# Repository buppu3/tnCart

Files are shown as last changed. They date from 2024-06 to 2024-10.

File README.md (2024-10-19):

# tnCart
TangNano20K を搭載した MSX 用カートリッジ。WonderTANG 対応版は [tnCartWonder](https://github.com/herraa1/tnCartWonder) をご参照ください。

- [カートリッジ基板](#カートリッジ基板)
- [たぶん動く機能](#たぶん動く機能)
- [今後の予定](#今後の予定)
- [対応する予定がない機能](#対応する予定がない機能)
- [使用モジュール](#使用モジュール)
- [メモ](#メモ)

## 使い方

- [FPGAビットストリーム、BIOSイメージのインストール方法](https://github.com/buppu3/tnCart/blob/main/doc/flash.md)
- [メガロムエミュレータの使い方](https://github.com/buppu3/tnCart/blob/main/doc/megarom.md)
- [機能のカスタマイズ](https://github.com/buppu3/tnCart/blob/main/doc/config.md)

## カートリッジ基板
回路は WonderTANG V1.01c のピンアサインとほぼ同じ(MSEL0_33 と MSEL1_33 が逆みたいです)で、バッファ IC は2電源タイプに変更してます。
また、信号の衝突を防ぐために INT 信号はオープンコレクタに変更してあります(WonderTANG V1.02d 相当)。

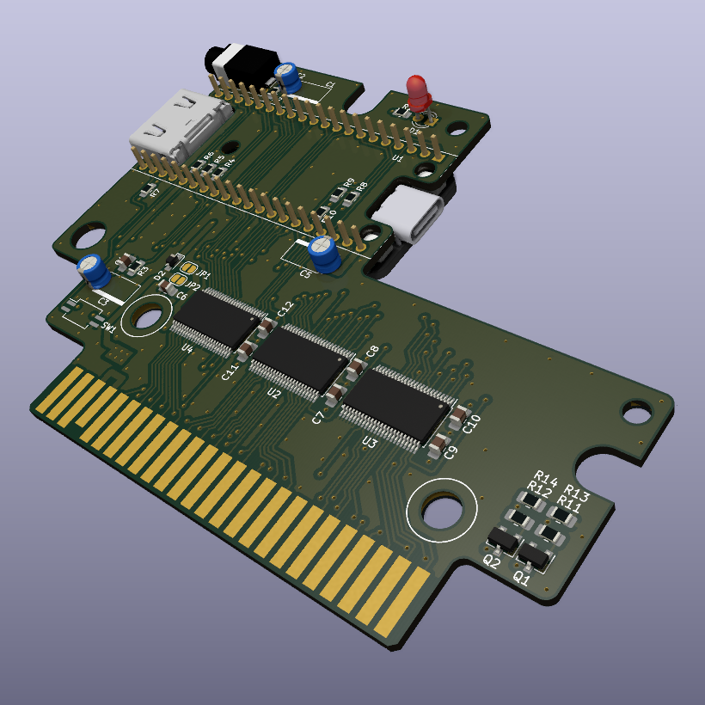
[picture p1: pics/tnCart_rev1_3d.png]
基板イメージ
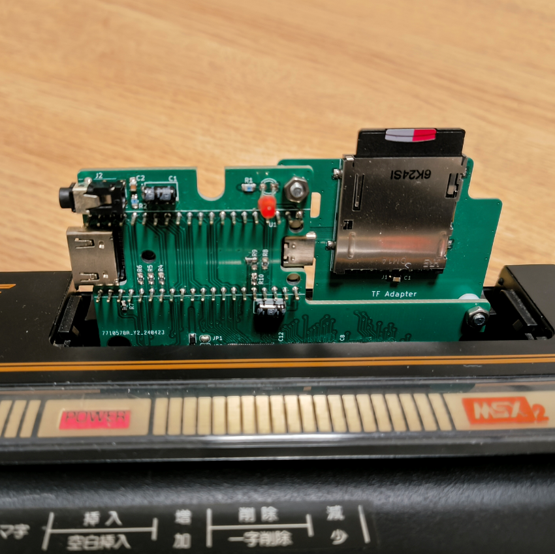
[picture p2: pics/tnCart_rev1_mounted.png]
スロットに装着したカートリッジ基板


## たぶん動く機能
- 4MB 拡張 RAM
- NEXTOR と TF カード制御
- メガロムエミュレーション
- SCC/SCC-I 音源
- FM 音源(OPLL)カートリッジ(拡張 BASIC は未対応)
- SCC + OPLL + PSG 音源の 3.5mmフォンジャック出力
- PAC 機能(~~まだデータ保持機能が実装されていませんので、電源を切るとデータは消えます~~)
- V9990 エミュレーション(「[msx-samurai](https://github.com/albs-br/msx-samurai)」,「[MSXgl](https://github.com/aoineko-fr/MSXgl) V9990サンプルの一部」,「[TINY野郎氏のテックデモ](https://www.youtube.com/watch?v=I6kXyMaED0s)」がそれなりに動く程度)

### MSXglサンプル
https://github.com/user-attachments/assets/6ccc81ad-7539-472d-90ff-44e20a4ad2ab

### msx-samurai
https://github.com/user-attachments/assets/eceabaee-c464-4074-b1bb-01007c4406e5

### TINY野郎氏のテックデモ1
https://github.com/user-attachments/assets/5c7b5b81-0413-4705-99fa-486552f4d58d

### TINY野郎氏のテックデモ2
https://github.com/user-attachments/assets/f6615e37-0041-4baa-8b7d-7cd3aba46d73

## 今後の予定
- V9990 のカーソル EOR 処理
- V9990 の B0(192x240) モード
- 回路と基板の修正(WS2812を点灯しないようにする等)

## 対応する予定がない機能
下記の機能は、しばらく(もしくは永遠に)対応する予定がありません
- V9990 の B5(640x400),B6(640x480)モード
- V9990 の画面補正機能(R#16)
- V9990 の漢字ROM
- HDMI による音声出力(ライセンス的に難しい)

## 使用モジュール
各機能の実装に下記モジュールを使用しています。
- PSG https://github.com/dnotq/ym2149_audio
- OPLL(VM2413) https://github.com/hra1129/one-chip-msx-kai/tree/main/source/pld/src/sound/opll/vm2413
- OPLL(IKAOPLL) https://github.com/ika-musume/IKAOPLL
- SCC(IKASCC) https://github.com/ika-musume/IKASCC

## メモ
- V9990 の映像は 720x480ドット(ピクセルクロック約27MHz) の DVI 信号で出力されます。接続するモニターやビデオキャプチャー機器によっては正常に動作しない可能性があります。

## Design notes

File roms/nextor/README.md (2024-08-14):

# NEXTOR カーネルロムイメージ

Nextor を使用する場合は、Gowin Programmer で EEPROM の 100000h へカーネル ROM を書いてください。
カーネル ROM ファイルは Nextor 公式( https://github.com/Konamiman/Nextor/releases )で配布されている "Nextor-2.1.2.MegaFlashSDSCC.1-slot.ROM" を使用してください。
ファイルの拡張子を全て小文字で bin へ変更しないと Gowin Programmer が正常に動作しませんので注意してください。

When using Nextor, you must write the ROM file to address 100000h using "Gowin Programmer".
The current version works with the officially distributed ROM file "Nextor-2.1.2.MegaFlashSDSCC.1-slot.ROM".
Gowin Programmer will not work properly unless you change the ROM file extension to ".bin".

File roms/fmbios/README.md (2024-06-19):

## FM BIOS ROM

アプリケーションに OPLL を検出させるための ROM ファイルです。
拡張 BASIC や ROM 内蔵音色は使用できません。

ファイルの拡張子を全て .rom から .bin へ変更し、Gowin Programmer を使用して 120000h へ書き込んでください。

This is a ROM file that allows applications to detect OPLL.
When using OPLL, you need to write this ROM file to address 120000h using "Gowin Programmer".

This ROM does not support BASIC statements and instrument data read from the ROM.
Gowin Programmer will not work properly unless you change the ROM file extension to ".bin".

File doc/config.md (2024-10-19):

## 機能のカスタマイズ
機能の設定、メモリ配置は config.sv で変更できます。ファイルを変更後、GowinSynthesis でビットストリームを合成してください。合成時、機能の有無でタイミング制約ファイル(sdcファイル)がエラーになりますので、適宜修正してください。

### フラッシュメモリ
FLASH_ADDR_, FLASH_SIZE_ パラメータで各機能に使われるフラッシュメモリのアドレスとサイズを設定できます。

### SDRAM
RAM_ADDR_ パラメータで各機能に使われる RAM のアドレスを設定できます。

### 音量バランス
ATT_EXT_ パラメータで 3.5mm フォンジャック出力の調整、ATT_INT_ パラメータで本体音声の調整ができます。  
MUL と DIV の比率で指定します。例えば出力を 0.5倍にするときは、MUL = 1, DIV = 2 を指定してください。

| パラメータ | 内容 |
| --- | --- |
| ATT_EXT_PSG_MUL<br/>ATT_EXT_PSG_DIV | PSG 音源 3.5mm フォンジャック出力 |
| ATT_EXT_FM_MUL<br/>ATT_EXT_FM_DIV | FM 音源 3.5mm フォンジャック出力  |
| ATT_EXT_MEGAROM_MUL<br/>ATT_EXT_MEGAROM_DIV | SCC 音源 3.5mm フォンジャック出力 |
| ATT_INT_FM_MUL<br/>ATT_INT_FM_DIV | FM 音源 本体出力 |
| ATT_INT_MEGAROM_MUL<br/>ATT_INT_MEGAROM_DIV | SCC 音源 本体出力 |

### 機能の ON/OFF
ENABLE_* パラメータで各機能の ENABLE/DISABLE を設定できます。
| パラメータ | 内容 |
| --- | --- |
| ENABLE_MEGAROM  | メガロムエミュレータおよび SCC 機能の有効(ENABLE または ENABLE_MEGA_SCC または ENABLE_MEGA_SCC_I)/無効(DISABLE)を設定します。 |
| ENABLE_FM | FM 音源および PAC 機能の有効(ENABLE_IKAOPLL または ENABLE_VM2413)/無効(DISABLE)を設定します。 |
| ENABLE_NEXTOR | NEXTOR および TF カード機能の有効(ENABLE)/無効(DISABLE)を設定します。 |
| ENABLE_RAM | 拡張 4MB RAM 機能の有効(ENABLE)/無効(DISABLE)を設定します。 |
| ENABLE_PSG | PSG 出力機能の有効(ENABLE)/無効(DISABLE)を設定します。 |
| ENABLE_SCC | SCC 出力機能の有効(ENABLE または ENABLE_IKASCC)/無効(DISABLE)を設定します。 |
| ENABLE_V9990<br/>ENABLE_V9990_CMD | V9990 エミュレータの有効(ENABLE)/無効(DISABLE)を設定します。|
| ENABLE_PAC_WRITE | PAC データをフラッシュへ記録するか(ENABLE)/記録しないか(DISABLE)を設定します。 |
| ENABLE_SCANLINE | アップスキャン時に走査線の隙間あり(ENABLE)/隙間なし(DISABLE)を設定します。 |

## 備考
~~V9990 機能を有効にする際は、config.sv の ENABLE_V9990, ENABLE_V9990_CMD を 1 に、ENABLE_FM, ENABLE_PSG, ENABLE_SCC 等を 0 に変更してから論理合成してください。全ての機能を有効にした状態では回路の規模が大きくなるため、TangNano20K では合成できません。~~

現在のバージョンは TangNano20K にギリギリ収まるサイズに最適化したので ENABLE_V9990, ENABLE_V9990_CMD, ENABLE_FM, ENABLE_PSG, ENABLE_SCC はすべて ENABLE になっています。  

Gowin Synthesis のバージョンで出力されるネットリストが違いますので、合成後は Time Analysis Report を確認した方がよいです(私は V1.9.9_x64で合成しています)。

~~IKASCC は 1chip MSX では MUX されたバスタイミングが合わないため動きません。~~

ENABLE_IKASCC 指定時は SCC-I 音源は使えません。

ENABLE_MEGAROM に ENABLE_MEGA_SCC または ENABLE_MEGA_SCC_I を指定すると tncrom.com を使用せずに SCC/SCC-I を有効にできます。

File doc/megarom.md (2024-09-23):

## メガロムエミュレータの使い方
メガロムエミュレータを利用する時は、tncrom コマンドを使用して ROM イメージを tnCart のメモリに転送する必要があります。

### tncrom のダウンロード
[tncrom.com](https://github.com/buppu3/tnCart/raw/main/tools/tncrom/bin/TNCROM.COM)をダウンロードし、Nextor をセットアップしたストレージにコピーしてください。

### ROM イメージ転送
Nextor を起動し、tncrom を実行してください。
~~~Shell
tncrom -T [ROMタイプ識別子] -R -O [イメージファイルのパス]
~~~

- -R オプションを指定するとROMイメージを転送後に MSX にリセットをかけます。
- -O オプションを指定するとリセットでメガロムエミュレータを無効にします(-O が未指定時は MSX の電源を OFF にするまでメガロムエミュレータが有効)。
- -T オプションで ROM のタイプを指定します。
- -N オプションでイメージファイルの転送を行いません。

ROMタイプに指定できる識別子は下記の通りです。
| ROMタイプ識別子 | ROMタイプ |
| --- | --- |
| 32K | 32KB ROM |
| 16K | 16KB ROM(ページ1) |
| 16K2 | 16KB ROM(ページ2) |
| ASCII16 | メガロム ASCII 16KB バンク |
| ASCII8 | メガロム ASCII 8KB バンク |
| KONAMI | メガロム コナミ 8KB バンク(SCC音源有効) |
| KONAMI_SCC_I | メガロム コナミ 8KB バンク(SCC-I有効) |
| KONAMI_WO_SCC | メガロム コナミ 8KB バンク(SCC音源無効) |
| R-TYPE | メガロム R-TYPE |

### コマンドラインの例
激突ペナントレース
~~~Shell
tncrom -T KONAMI -R -O GEKIPENA.ROM
~~~

R-TYPE
~~~Shell
tncrom -T R-TYPE -R -O R-TYPE.ROM
~~~

msx-samurai
~~~Shell
tncrom -T ASCII16 -R -O SAMURAI.ROM
~~~

MSXgl V9990 sample
~~~Shell
tncrom -T 32K -R -O S_V9990.ROM
~~~

TINY野郎氏の V9990 テックデモ
~~~Shell
tncrom -T ASCII16K -R -O DEMO9990.ROM
~~~

### SCC を有効にする
SCC を有効にする
~~~Shell
tncrom -T KONAMI -N
~~~

SCC-I を有効にする
~~~Shell
tncrom -T KONAMI_SCC_I -N
~~~

### その他
音楽プレーヤーや SofaRun 等を頻繁に利用する場合は、AUTOEXEC.BAT に "tncrom -T KONAMI_SCC_I -N" を追加すると便利です。

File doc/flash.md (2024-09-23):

# FPGA ビットストリーム、BIOS イメージのインストール方法

## ファイルのダウンロード

下記の3ファイルをダウンロードしてください。拡張子の .rom は .bin へリネームして保存してください。

- [tnCart_board_rev1.fs](https://github.com/buppu3/tnCart/raw/main/rtl/impl/pnr/tnCart_board_rev1.fs)
- [fmbios.rom](https://github.com/buppu3/tnCart/raw/main/roms/fmbios/bin/fmbios.rom)
- Nextor 公式( https://github.com/Konamiman/Nextor/releases )で配布されている "Nextor-2.1.2.MegaFlashSDSCC.1-slot.ROM"

## Flash プログラム方法(Windows GUI)

### 準備
カートリッジが MSX から外れていることを確認し、TangNano20k の USB-C コネクタと PC の USB コネクタをケーブルで接続してください。
**tnCart と PC を接続したまま MSX へカートリッジを差し込むと、MSX や PC が故障する可能性がありますのでご注意ください。**

GowinProgrammer を起動してください。  

ケーブル選択表示がでますので、**SAVE**をクリック  
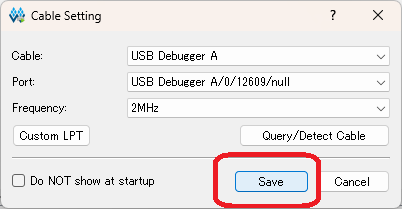
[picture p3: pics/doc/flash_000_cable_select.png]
ケーブル選択

  
もし、この表示が出たら場合は USBの接続を確認して[Query/DetectCable]をクリックし、その次に[SAVE]をクリック  
no usb  
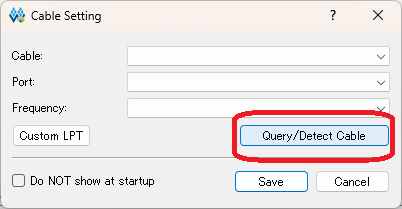
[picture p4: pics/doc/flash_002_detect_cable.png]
DetectCable

  
**Scan Device**をクリックする  
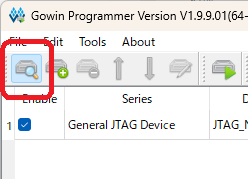
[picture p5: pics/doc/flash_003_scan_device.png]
ScanDevice

  
デバイス選択表示で[GWAR-18C]を選び[OK]をクリック  
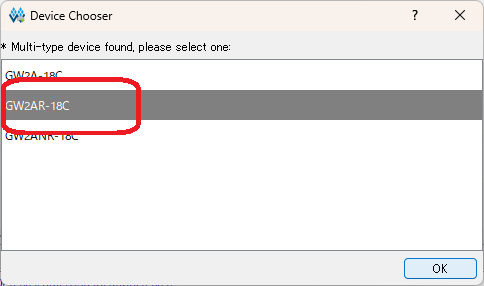
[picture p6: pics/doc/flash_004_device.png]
Device選択

  
### FPGA ビットストリームの書き込み

**Configure Device**をクリックし、設定を開きます  
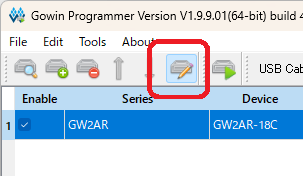
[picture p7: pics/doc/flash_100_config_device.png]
ConfigDevice

  
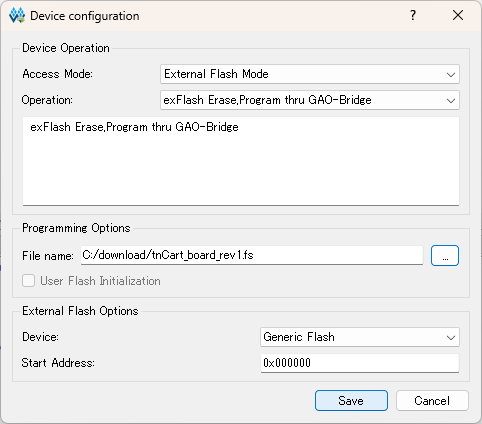
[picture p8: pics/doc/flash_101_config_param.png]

  
| 項目 | 設定する内容 |
| --- | --- |
| AccessMode | External Flash Mode |
| Operation | exFlash Erase, Program thru GAO-Brige |
| Device | Generic Flash |
| StartAddress | 0x000000 |
| Filename | ...をクリックして、tnCart_board_rev1.fsを選択(使いたいビットストリームのファイルを選択) |

設定を変更したら、**Save**をクリック  
  
**Program/Configure**をクリックし、Flash へ Program します。  
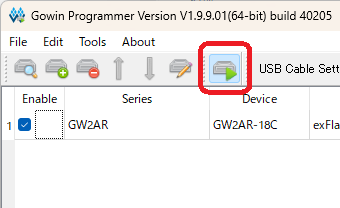
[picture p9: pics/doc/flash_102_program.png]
program

  
しばらく待つとフラッシュへのプログラムが完了します。  
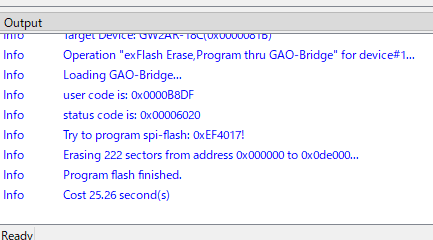
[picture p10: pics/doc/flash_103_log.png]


### Nextor カーネルの書き込み

**Configure Device**をクリックし、設定を開きます  
ConfigDevice
  
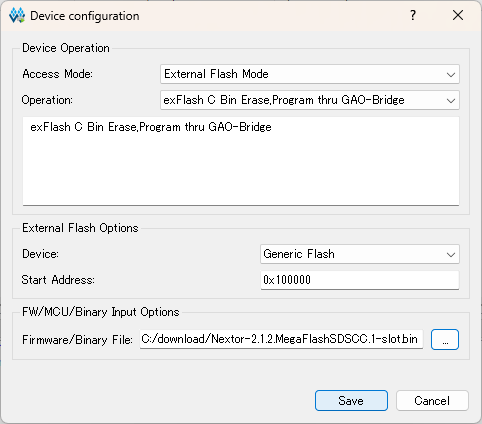
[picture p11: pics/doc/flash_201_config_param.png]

  
| 項目 | 設定する内容 |
| --- | --- |
| AccessMode | External Flash Mode |
| Operation | exFlash C Bin Erase, Program thru GAO-Brige |
| Device | Generic Flash |
| StartAddress | 0x100000 |
| Filename | ...をクリックして、Nextor-2.1.2MegaFlashSDSCC.1-slot.binを選択 |

**Save**をクリック  
  
**Program/Configure**をクリックし、Flash へ Program します。  
program
  
しばらく待つとフラッシュへのプログラムが完了します。  
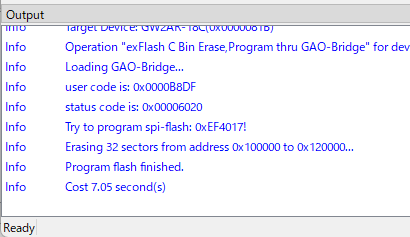
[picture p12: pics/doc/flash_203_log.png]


### FM BIOS の書き込み

**Configure Device**をクリックし、設定を開きます  
ConfigDevice
  
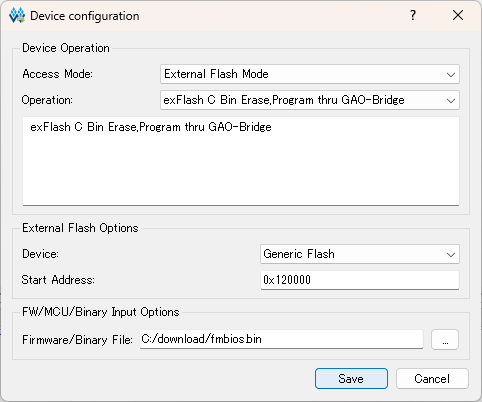
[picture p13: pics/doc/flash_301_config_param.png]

  
| 項目 | 設定する内容 |
| --- | --- |
| AccessMode | External Flash Mode |
| Operation | exFlash C Bin Erase, Program thru GAO-Brige |
| Device | Generic Flash |
| StartAddress | 0x120000 |
| Filename | ...をクリックして、fmbios.binを選択 |

**Save**をクリック  
  
**Program/Configure**をクリックし、Flash へ Program します。  
program
  
しばらく待つとフラッシュへのプログラムが完了します。  
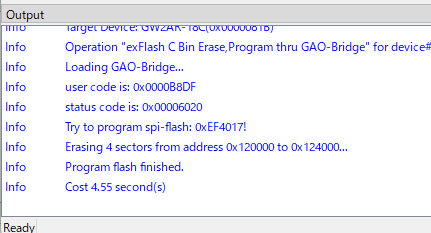
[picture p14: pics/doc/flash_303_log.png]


### 終了と起動

GowinProgrammer を終了し、TangNnano20kから USB ケーブルを外してください。  
MSX の電源が OFF であることを確認し、カートリッジを MSX へ差し込んでください。  
カートリッジが正しく差し込まれていることを確認したら、MSX の電源をONにします。  

## Flash プログラム方法(Windows CUI)

### 準備
カートリッジが MSX から外れていることを確認し、TangNano20k の USB-C コネクタと PC の USB コネクタをケーブルで接続してください。
**tnCart と PC を接続したまま MSX へカートリッジを差し込むと、MSX や PC が故障する可能性がありますのでご注意ください。**

コマンドプロンプトを起動し、programmer_cli.exe があるディレクトリにカレントディレクトリを変更してください。

### FPGA ビットストリームの書き込み
"exFlash Erase,Program thru GAO-Bridge" で 0x000000~ に書き込みます。
~~~Shell
programmer_cli -d GW2AR-18C -r 36 -f download\tnCart_board_rev1.fs
~~~

### Nextor カーネルの書き込み
"exFlash C Bin Erase,Program thru GAO-Bridge" で 0x100000~ に書き込みます。
~~~Shell
programmer_cli -d GW2AR-18C -r 38 --spiaddr 0x100000 -f \download\Nextor-2.1.2.MegaFlashSDSCC.1-slot.bin
~~~

### FM-BIOS の書き込み
"exFlash C Bin Erase,Program thru GAO-Bridge" で 0x120000~ に書き込みます。
~~~Shell
programmer_cli -d GW2AR-18C -r 38 --spiaddr 0x120000 -f \download\fmbios.bin
~~~

### 終了と起動
すべてのイメージの書き込みが完了したら、USB-C ケーブルを外し、tnCart を MSX のカートリッジスロットへ差し込んでください。
カートリッジを挿入後、MSX の電源を入れてください(tnCart を MSX に接続すると MSX の起動が 1秒程遅くなります)。

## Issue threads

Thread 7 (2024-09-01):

V9990 の DVI 出力がビデオキャプチャーできない

buppu3, 2024-09-01:
GC533(HDMI ビデオキャプチャー)の最新ファームウェアでキャプチャができなくなった。
V9990 エミュレーションのドットクロックタイミングは MSX バスクロックから生成しているが、MSX バスクロック (約3.58MHz) と DIV ドットクロック(27Mhz) の同期がとれず、VSYNC のタイミングがフレーム毎にブレてしまい信号が安定しない為。

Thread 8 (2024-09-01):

1chip MSX で Nextor の仮想 FD の動作がおかしい

buppu3, 2024-09-01:
1chip MSX 上で tnCart の Nextor から仮想 FD のゲームを起動すると、ブート時に画面が暗いまま固まる。
FS-A1F では問題が発生しない。

buppu3, 2024-09-01:
1chip MSX 内蔵の DISK BIOS 有効時のメモリが不足が原因。
内蔵 DISK BIOS を無効にしても、特定のソフト(あ～くしゅ)は起動時にハングアップする。

buppu3, 2024-09-07:
プログラムが用意したスタック領域が小さすぎて暴走している現象を確認

あーくしゅ起動すると、下記の動作を行う

1. BDOS のセクタリードで セクター#8~#31 を 0100h～ に読み出し、0100h へジャンプ
2. スタックポインタを 0100h に設定
3. 0080h～0084h にサブルーチンを転送
4. BDOS で セクター#1438を読み出し
5. インタースロットコールで RAM の 0080h を呼び出し

1chipMSXで起動すると 4 の実行中に VSYNC 割り込みが発生し、Nextor の BDOS 処理と BIOS の割り込み処理がスタックを 123バイトを超えて使用してしまい、0080h～0084h の内容を破壊してしまう。その後に 5 で 0080h をコールすると意味のないコードを実行し暴走してしまう。

buppu3, 2024-09-07:
パッチをあててスタック領域を増やしても動作しない。

Nextor の割り込みルーチンが E3B7h～にあるが、ゲームのプログラムが E000h へ 2セクタ分のデータを読み出して、割り込みルーチンを破壊している。
FS-A1F の場合も内蔵ドライブを無効にしてゲームを起動すると暴走することを確認した。

Closed 2024-09-07.

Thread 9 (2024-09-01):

1chip MSX で FM 音源が認識されない

buppu3, 2024-09-01:
1chip MSX で FM 音源が 3.5mm ジャックから出力されない

buppu3, 2024-09-01:
原因は 1chip MSX に MSX-MUSIC が載っているのでカートリッジ側が OPLL I/O ポートが有効にならない。

3.5mm ジャックからは常に音を出力したいので、7FF6h のスイッチで I/O ポートの Enable/Disable を制御せずに、MSX 側へ出力する音の ON/OFF を制御するようにするべき?

Closed 2024-09-01.

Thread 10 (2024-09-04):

WonderTANG 1.02d board compatibility

herraa1, 2024-09-04:
First, thanks for your awesome project and for making it public so we all can learn from you.

I noticed that your tnCart board is using (mostly) the same tn20k signal mapping as the WonderTANG 1.02d.
The only difference is that the WonderTANG MSEL0_33 signal is mapped to tnCart MSEL1_33 and WonderTANG MSEL1_33 is mapped to tnCart MSEL0_33. Other than that the two board designs are "equivalent".

I made a small modification to the tnCart RTL to accomodate the difference with the WonderTANG and tested that the FPGA code works nicely too on the WonderTANG 1.02d.
Making it work with the WonderTANG 2.0b required a few more changes because the signal mapping is slightly different and the audio signal is sent to the internal tn20k dac using I2S, but I also did a quick (really dirty) test and it works too.

This was discussed at [msx.org](https://www.msx.org/forum/msx-talk/hardware/wondertang-who-wants-to-juice-up-your-msx?page=44) .

I was wondering if you are interested in making your tnCart FPGA RTL compatible with the WonderTANG 1.02d and what would be your preference in achieving that:
- One option could be changing your tnCart board design to make MSEL0_33 select A0-A7 and MSEL1_33 select A8-A15 as in the WonderTANG, that would make your RTL directly useable on the WonderTANG 1.02d and the tnCart.
- Another option would be to have a config option to select between the two boards at bitstream build time and generate different bitstreams for each of them. This option could be used too for making the tnCart FPGA code compatible with the WonderTANG 2.0 (probably with a different project to select different constraint files for both the physical constraints .sdc due to the different IO mapping and maybe timing constraints .cst to account for the new CLK signal for the I2S transmitter to the tn20k internal DAC).

Regarding audio, I think that the WonderTANG 1.02d audio (using the fpga 1-bit DAC) is cleaner (less plagued with noise and interference) than the WonderTANG 2.0b audio (using the tn20k DAC, which amplifies even more the noises). This happens both with the WonderTANG fpga code and your (modified) tnCart fpga code.
So I'm not sure if it is worth investing time in the WonderTANG 2.0, unless there is a way to make the audio cleaner.

What do you think about the tnCart FPGA compatibility with the existing WonderTANG boards?

Thanks!

buppu3, 2024-09-05:
Thank you for your interest in tnCart.

I have concerns with the current tnCart circuit and I will be modifying the circuit in the near future. After this modification, tnCart and WonderTANG will no longer be pin compatible.

So, in order to maintain compatibility between the different boards, I think it would be best to create a project with a modified .sdc for each board and synthesize a bitstream for each.

herraa1, 2024-09-05:
Thanks for your comments.

Would you prefer the WonderTANG compatibility changes handled by others in an external fork of you repository (so that you can focus just on tnCart)? Or would you accept pull requests for WonderTANG boards in your repo?

Thanks again.

buppu3, 2024-09-07:
I can't confirm WonderTANG V2.0 compatible works, so I can't respond quickly to pull requests.
Considering this, I think it is better to handle the forked code in your repository.

Please take it in consideration.

herraa1, 2024-09-07:
Sure, that makes sense.
I'll handle those modifications in a separate fork.

Thanks a lot again.

herraa1, 2024-09-07:
Just for you reference, the mentioned fork is available at [https://github.com/herraa1/tnCartWonder](https://github.com/herraa1/tnCartWonder).

I'm closing the issue.

Thank you.

DFL1973, 2024-09-08:
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

How about a bitstream for wondertang v1.01c? Should be almost the same as 1.02d, except for the INT line (inverted?)

herraa1, 2024-09-14:
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

I pushed the required changes and a bitstream (without V9990) for V1.01c.

taupter, 2024-09-15:
It would be nice to have one that works with the WonderTang that Victor
Trucco sold.

Em sáb., 14 de set. de 2024 16:01, herraa1 ***@***.***>
escreveu:

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

herraa1, 2024-09-15:
> It would be nice to have one that works with the WonderTang that Victor Trucco sold.

You may need to ask Victor Trucco which version from Luis Antoniosi is equivalent to the one(s) he sold and then try to use the bitstream for that version.

vtrucco, 2024-09-29:
> > It would be nice to have one that works with the WonderTang that Victor Trucco sold.
>
> You may need to ask Victor Trucco which version from Luis Antoniosi is equivalent to the one(s) he sold and then try to use the bitstream for that version.

V1.01c.

Closed 2024-09-07.

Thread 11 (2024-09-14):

SofaRun and MGSP do not detect the SCC

herraa1, 2024-09-14:
SofaRun 8.1 (with SofaROM 3.3) does not autodetect the SCC from tnCart. When manually specifying the slot location of the SCC (1-2) SofaRun complains that the SCC and Memory Mapper share the same slot.

MGSP 2.1.3 does not detect the SCC from tnCart (and shows "SCC SLOT #none" when loading). The FM is properly detected.

I don't know if something can be changed in tnCart to fix that, or if the mentioned tools need to be updated to support the tnCart.

Thanks.

buppu3, 2024-09-15:
I checked the behavior of SofaRun (SofaROM v3.3) on tnCart cartridges

- tnCart(SCC-I) detected successfully
- tnCart (SCC) is not detected; it is detected by setting the External SCC setting to Yes in SofaRun. Also, a warning will be shown.
- "Gekitotsu pennant race"(Real SCC cartridge) is not detected; it is detected by setting the External SCC setting to Yes in SofaRun.

The tnCart board detects SCC as well as the real thing, and SCC output in SofaRun seems to be fine.
Furthermore, SCC is also detected in the MGSP.

I think the reason why SCC is not detected by tnCartWonder is the same as #12.

Also, I don't know why SofaRom is displaying the warning. If the primary slots are identical, what is the problem?

herraa1, 2024-09-15:
I've seen in one of your twitter posts how you manage to make MGSP (and SofaRun) work.
You first load TNCROM with option /N and no ROM, then load the program you want to use with the SCC.

I tested it and it works perfectly (both MGSP and SofaRun).

TNCROM /T KONAMI_SCC_I /N
SR
or
MGSP

So the detection problem is not related to #12, it is simply that the SCC needs to be activated first because it is not active by default (as in the WonderTANG! fpga code for example).

Thanks for your comments.

Closed 2024-09-16.

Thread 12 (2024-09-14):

Car sprites do not show properly when F1 Spirit is loaded with TNCROM

herraa1, 2024-09-14:
When running F1 Spirit via `TNCROM.COM` ver 0.03 (but it happens too in older versions) the car sprites can't be seen correctly (some are missing, some move erratically) when a race starts.

The test was done with F1SPIRIT.ROM with md5 603d4c819a51d0c20ff9fa9f902d3ffd, and the command used to load the ROM was `TNCROM.COM /T KONAMI /R F1SPIRIT.ROM`

It fails in the same way with new type `KONAMI_SCC_I`.

On the other hand the game works fine when loaded with SofaROM, but then the SCC is not detected as indicated in #11.

Any clues? Thanks.

buppu3, 2024-09-15:
I have done the same experiment with tnCart cartridges, but could not reproduce the phenomenon.

I suspect that the MEGAROM emulator bus is unstable, since the SCC also has symptoms that cannot be detected.
Was this symptom present in the first version of tnCartWonder?

herraa1, 2024-09-15:
The sympton is present on all WonderTANG! revision boards when using the tnCart fpga code.
This happened always since initial versions of the tnCartWonder modifications.

tnCartWonder modifications for V1.02d (and V1.01c) are minimal: just the little MSEL0 swap for MSEL1 (and inversion of the INT signal for V1.01c), the rest is exactly 100% as in the tnCart), and I can reproduce the problem always.

I tested it also with several MSX machines (Panasonic FS-A1WSX, Toshiba HX-10, Philips VG8235) and it always happens irrespective of the machine used.

Can you post the md5sum of your F1 Spirit ROM? Althought it works perfectly with SofaRun (and now with SCC working if I activate the SCC before loading SR) maybe my particular ROM has problems with TNCROM.

Thank you.

buppu3, 2024-09-15:
I checked the TNCROM source files and found a bug that corrupts the transfer data.
I don't know if this is the cause, but I have committed a new TNCROM for you to check out.

herraa1, 2024-09-15:
I tested the new TNCROM 0.04 with a WonderTANG! V2.0b on my Panasonic FS-A1WSX (which is my most stable configuration).

First I used the tnCartWoder firmware with the mux sampling "workarounds" I added and got the same results.

I was going to post about it but decided to test again using the tnCartWonder code without the mux sampling "workarounds" (but with the code to set the rgb led to red on poweron) and, this time it worked!

The problem is that without the "workarounds" other MSX machines do not work at all or hang randomly.

The mux sampling code for the WonderTANG! boards seems to be a problem.
It was a problem on the WonderTANG! fpga code (my Omega worked or not depending on the specific mux sampling code... and it stopped working with V2.0b) and seems to still be a source of problems.

I need to make more tests to confirm that the problem went away too on the other machines without the mux sampling code workarounds (if I manage to get to that point before they hang).

herraa1, 2024-09-15:
I did one more quick test with my Toshiba HX-10 (which is also pretty stable).

I can confirm that (without mux sampling workarounds) the game works correctly with TNCROM v0.04 and fails (sprites show on the top of the screen) with TNCROM v0.03.

buppu3, 2024-09-16:
Regarding the instability in V2.0, there are the following possibilities.

- The circuit scale has become larger, and more wiring is being rerouted in the FPGA, resulting in signal delays.
- Memory access timing is off because the MUX cycle has increased by one clock cycle.

If the first is the cause, the only solution is to modify the source code to reduce the size (Or adjust the entire system to run at a lower frequency)

If the second cause is the cause, adjusting the following timing may improve the situation.
- Length of delay put into RDn and WRn (Delay is intentionally put in because the RDn/WRn signals have no delay compared to the signal being MUXed)
- DELAY and MRAM_EXEC_DELAY parameters in uma.sv (Memory access timing is synchronized with the CPU clock, and RDn/WRn is checked at the timing of 6 operating clocks from the rising edge of 3.58 MHz clock)

Adjusting these two delays may help stabilize the operation.

herraa1, 2024-09-18:
Thanks for your comments.

I think we can close this issue as the subject has been fixed with commit cfe66c51a5c41dbddce8ebf01cfbc06c9bc7952f.

If needed we can open a new specific issue focused on the detected instabilities.
For now, the mux code tweaks were reverted. I'll keep an eye on possible instabilities once #14 is fixed.

Closed 2024-09-18.

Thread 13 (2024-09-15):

SCC-I 音源が使用できない

buppu3, 2024-09-15:
SCC-I音源レジスタのバンクチェックは Megarom.BankReg の MSB をチェックしているが、上位2ビットが1になることが無いので音源のレジスタへアクセスできない。

```
        always_ff @(posedge CLK or negedge RESET_n) begin
            if(!RESET_n)                      scc_bank_n <= 1;
            else if(!ExtBus[BUS_SCC].RESET_n) scc_bank_n <= 1;
            else if(scc_mode_scci)            scc_bank_n <= Megarom.BankReg[{ExtBus[BUS_SCC].ADDR[15], ExtBus[BUS_SCC].ADDR[13]}][7] != 1'b1;
            else                              scc_bank_n <= Megarom.BankReg[{ExtBus[BUS_SCC].ADDR[15], ExtBus[BUS_SCC].ADDR[13]}][5:0] != 6'b111111;
        end
```

Megarom.BankReg に設定される値は Megarom.BankRegMask でマスクされる。
```
                else if(det_wr && ((Bus.ADDR & Megarom.BankRegAddrMask) == Megarom.BankRegAddr[bank_num]) && BankEnable[bank_num]) begin
                    Megarom.BankReg[bank_num] <= Bus.DIN & Megarom.BankRegMask;
                end

```

Megarom.BankRegMask は TNCROM.COM の rom_table.c 内の値を使用するので、0x3F が設定されている。
```
const ROM_ATTR_t ROM_ATTR_KONAMI_SCC_I = {
    (uint8_t)(FLAG_SCC | FLAG_SCC_I),               // FLAGS
    (uint8_t)0x3F,                                  // BANK VALUE MASK
    (uint16_t)0xF800,                               // BANK REGISTER ADDRESS MASK
    {
        { (uint16_t)0x5000, 0, 0 },                 // BANK #0 REGISTER ADDRESS, INITIAL VALUE, RESERVED
        { (uint16_t)0x7000, 1, 0 },                 // BANK #1 REGISTER ADDRESS, INITIAL VALUE, RESERVED
        { (uint16_t)0x9000, 2, 0 },                 // BANK #2 REGISTER ADDRESS, INITIAL VALUE, RESERVED
        { (uint16_t)0xB000, 3, 0 }                  // BANK #3 REGISTER ADDRESS, INITIAL VALUE, RESERVED
    },
    "KONAMI SCC-I"                                  // NAME
};
```

Closed 2024-09-16.

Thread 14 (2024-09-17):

Clock unstable during boot, tnCart stuck into boot loop

herraa1, 2024-09-17:
After reports of many users that latest tnCartWonder bitstreams were not booting into their MSXs when using WonderTANG! V2.0b boards (and strangely my Panasonic FS-A1WSX and Toshiba HX-10 were not affected, or at least rarely), I started troubleshooting the issue.

Users observed that their WonderTANG! V2.0b boards got stuck while booting, showing a continuous fast-blinking board led, and not progressing to the MSX boot screen (video was black).

I made a minimal tnCart configuration for my WonderTANG! V2.0b with the bare minimum to make it wondertang-compatible, i.e.:
- use the current tnCart code, without tweaks (and without adding the i2s transmitter for the MAX98357A)
- swap MSEL0 and MSEL1
- add the required pin mappings for WonderTANG! V2.0b
- leave the external and internal sound outputs unconnected

User pakoto from msx.org (thanks!) help me making tests remotely with his WonderTANG! V2.0b and his Panasonic FS-A1 (and a Sanyo MSX1) which he was reporting were failing 100% of the time.
Using that bare minimum setup we observed indeed the same boot loop with the fast-blinking board led.

I started suspecting that something was going on during the boot process, before freeing the MSX to boot.

I changed a bit the setup so that I could use the LED output for debugging some signals, connecting it to a logic analyzer.
I diagnosed the CLK_MEM_READY signal through the LED pin (IO 75) and saw that during all those failed boots, the CLK_MEM_READY was deasserted before the bootloader had time to complete, causing a RESET and provoking the boot loop.

I thought what change could have caused that problem, and remembered that in commit 62a343aea63ec7127754807950ec2bd71299bfeb "Fix #7 Synchronize the operating clock with the bus clock" you switched the clock for deriving the base clock for the fpga from the 27MHz clock of the Tang Nano 20k to the 3.58MHz of the cartridge clock.

To confirm if that was the issue, and without further analyzing the root cause of the clock not being stable for the whole bootloader phase, I did a quick test switching the base clock to the old 108MHz derived from the 27MHz Tang Nano 20k (just the CLK_MEM, without touching anything else for a quick test).

So basically commenting out this:

```
/*
    wire CLK_MEM_LOCK;
    assign CLK_MEM_READY = RESET_n && CLK_MEM_LOCK;
    rPLL u_pll_base (
        .CLKOUT(CLK_MEM),
        .LOCK(CLK_MEM_LOCK),
        .CLKOUTP(CLK_MEM_P),
        .CLKOUTD(),
        .CLKOUTD3(),
        .RESET(!RESET_n),
        .RESET_P(1'b0),
        .CLKIN(CLK_IN),
        .CLKFB(1'b0),
        .FBDSEL({1'b0,1'b0,1'b0,1'b0,1'b0,1'b0}),
        .IDSEL({1'b0,1'b0,1'b0,1'b0,1'b0,1'b0}),
        .ODSEL({1'b0,1'b0,1'b0,1'b0,1'b0,1'b0}),
        .PSDA({1'b0,1'b0,1'b0,1'b0}),
        .DUTYDA({1'b0,1'b0,1'b0,1'b0}),
        .FDLY({1'b1,1'b1,1'b1,1'b1})
    );

    defparam u_pll_base.FCLKIN = "3.58";
    defparam u_pll_base.DYN_IDIV_SEL = "false";
    defparam u_pll_base.IDIV_SEL = 0;
    defparam u_pll_base.DYN_FBDIV_SEL = "false";
    defparam u_pll_base.FBDIV_SEL = 29;
    defparam u_pll_base.DYN_ODIV_SEL = "false";
    defparam u_pll_base.ODIV_SEL = 8;
    defparam u_pll_base.PSDA_SEL = "1000";
    defparam u_pll_base.DYN_DA_EN = "false";
    defparam u_pll_base.DUTYDA_SEL = "1000";
    defparam u_pll_base.CLKOUT_FT_DIR = 1'b1;
    defparam u_pll_base.CLKOUTP_FT_DIR = 1'b1;
    defparam u_pll_base.CLKOUT_DLY_STEP = 0;
    defparam u_pll_base.CLKOUTP_DLY_STEP = 0;
    defparam u_pll_base.CLKFB_SEL = "internal";
    defparam u_pll_base.CLKOUT_BYPASS = "false";
    defparam u_pll_base.CLKOUTP_BYPASS = "false";
    defparam u_pll_base.CLKOUTD_BYPASS = "false";
    defparam u_pll_base.DYN_SDIV_SEL = 2;
    defparam u_pll_base.CLKOUTD_SRC = "CLKOUT";
    defparam u_pll_base.CLKOUTD3_SRC = "CLKOUT";
    defparam u_pll_base.DEVICE = "GW2AR-18C";
*/
```

and adding this:

```
    wire CLK_MEM_LOCK;
    assign CLK_MEM_READY = RESET_n && CLK_MEM_LOCK;
    localparam FREQ=108_000;
    rPLL u_pll_base (
        .CLKOUT(CLK_MEM),
        .LOCK(CLK_MEM_LOCK),
        .CLKOUTP(CLK_MEM_P),
        .CLKOUTD(),
        .CLKOUTD3(),
        .RESET(!RESET_n),
        .RESET_P(1'b0),
        .CLKIN(CLK_27M),
        .CLKFB(1'b0),
        .FBDSEL(6'b000000),
        .IDSEL(6'b000000),
        .ODSEL(6'b000000),
        .PSDA(4'b0000),
        .DUTYDA(4'b0000),
        .FDLY(4'b1111)
    );
    defparam u_pll_base.FCLKIN = "27";
    defparam u_pll_base.DYN_IDIV_SEL = "false";
    defparam u_pll_base.IDIV_SEL = 0;
    defparam u_pll_base.DYN_FBDIV_SEL = "false";
    defparam u_pll_base.FBDIV_SEL = 3;
    defparam u_pll_base.DYN_ODIV_SEL = "false";
    defparam u_pll_base.ODIV_SEL = 8;
    defparam u_pll_base.PSDA_SEL = "1000";
    defparam u_pll_base.DYN_DA_EN = "false";
    defparam u_pll_base.DUTYDA_SEL = "1000";
    defparam u_pll_base.CLKOUT_FT_DIR = 1'b1;
    defparam u_pll_base.CLKOUTP_FT_DIR = 1'b1;
    defparam u_pll_base.CLKOUT_DLY_STEP = 0;
    defparam u_pll_base.CLKOUTP_DLY_STEP = 0;
    defparam u_pll_base.CLKFB_SEL = "internal";
    defparam u_pll_base.CLKOUT_BYPASS = "false";
    defparam u_pll_base.CLKOUTP_BYPASS = "false";
    defparam u_pll_base.CLKOUTD_BYPASS = "false";
    defparam u_pll_base.DYN_SDIV_SEL = 2;
    defparam u_pll_base.CLKOUTD_SRC = "CLKOUT";
    defparam u_pll_base.CLKOUTD3_SRC = "CLKOUT";
    defparam u_pll_base.DEVICE = "GW2AR-18C";

```

After that change, the WonderTANG! V2.0 of user pakoto started to boot 100% reliably in his Panasonic FS-A1 and Sanyo MSX1 without getting into the boot loop anymore (something that never happened before).

So, there is clearly a problem when using the CART_CLK, as at least in some MSX, the clock is not stable (and becomes not ready) in the middle of the bootloader process.

As I said, I didn't further analyze the root cause of it, but maybe it could be related to the following: as the CART_CLK comes from the CPU clock and the CPU clock comes from the VDP clock, maybe the fact that SYSRESET is help during bootloader causes the VDP to stop providing a clock. On some MSX that happens before than others, letting some of them complete the bootloader (and get to boot the MSX system) and others to get stuck into the dreaded boot loop.
And that explains too why when using the 27MHz clock to derive the base clock, the bootlopp never happens.

Of course, changing the clock that way was just to confirm the issue, and it is _NOT_ a proposed solution as that change has other implications, and you made that change to fix other issues.

So something needs to be thought to fix the problem the right way.

Looking forward for your comments.

buppu3, 2024-09-18:
Thanks for investigating this issue.

You have identified the following issues

- PLL lock is removed when cartridge clock is used.
- PLL lock is removed and SDRAM module is reset.
- SDRAM module resets, other modules also reset
- The BOOTLOADER module is repeatedly run, causing the LEDs to blink repeatedly.
- WAITn is still asserted and MSX will not boot (video was black)

### What causes the clock signal to be unstable?
You mentioned that the VDP clock may be stopped, but why is it repeating?
Will the power supply voltage fluctuate due to changes in load, causing unstable oscillation?

### About the problem when using with onboard 27MHz
Dot clock is generated in sync with 3.58MHz, causing jitter in the DVI output of the V9990 emulation, resulting in DVI devices that cannot be supported

If the SYNC_CLK_EN parameter of the UMA module is set to 0, the module will operate asynchronously and the DIV output will be stable.
However, I do not know how 4MB RAM, Nextor, and FM-BIOS will work under these conditions.
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
herraa1, 2024-09-22:
By the way, I just verified that the bootloop problem is not specific of the WonderTANG! V2.0b board, but it is also present in WonderTANG! V1.02d and WonderTANG! V1.01c boards.

And in WonderTANG! V1.02d the only difference is the swap of MSEL0 and MSEL1.

I think that the fact that DAC_SDMODE_n appears in the 27MHz tnCartWoder synthesis is just because it is combinatorially assigned to RESET_n, and then the synthesis tool may have replaced RESET_n by DAC_SDMODE_n with the same outcome.

The strange thing is the synthesis output you posted on the 3.58MHz tnCartWonder, where the RESET_n has been replaced by some expression depending on the blink count of the LED...

herraa1, 2024-09-22:
I just did another test.
I commented out the current LED code (so that the synthesis tool can't generate that weird output you showed), and replaced it with code to just turn on the LED when the TF Card is accessed (i.e. when LedNextor turns it on).

But the bootloop is still there when using the 3.58MHz clock (and gets fixed as soon as switching to the 27MHz clock).

```
diff --git a/rtl/src/peripheral/led.sv b/rtl/src/peripheral/led.sv
index 7f22f77..ea9f140 100644
--- a/rtl/src/peripheral/led.sv
+++ b/rtl/src/peripheral/led.sv
@@ -73,6 +73,7 @@ module LED #(
     output  reg     LedPort             // LED ポート
 );

+`ifdef COMMENT_OUT
     /***************************************************************
      * ディレイカウンタ
      ***************************************************************/
@@ -125,6 +126,10 @@ module LED #(
             LedPort <= (delay_count != 0) ? 1'b1 : 1'b0;
         end
     end
+`else
+    always_ff @(posedge CLK)
+        LedPort <= (LedNextor.State == LedNextor.LED_STATE_ON);
+`endif

 endmodule

```

buppu3, 2024-09-22:
When I checked again, I couldn't get any results that depended on the LED module, so I think it was a misunderstanding.

buppu3, 2024-09-22:
Since this problem cannot be resolved immediately, onboard 27 MHz will be used until the cause is identified.
Continue to investigate the cause of the problem, as it is not a root cause resolution.

buppu3, 2024-10-04:
I have observed a noise in the 3.58 MHz clock and a reboot of the boot loader. However, I do not know if this is the cause of the repeat.
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

buppu3, 2024-10-12:
The CART_CLOCK noise was reproducible and occurred immediately after the V9990 video output started.
However, it no longer occurs after cleaning the card edge terminals.
Did the buffer IC become unstable due to fluctuations in current consumption?

herraa1, 2024-10-29:
> The CART_CLOCK noise was reproducible and occurred immediately after the V9990 video output started. However, it no longer occurs after cleaning the card edge terminals. Did the buffer IC become unstable due to fluctuations in current consumption?

Note that in my original tests, the V9990 was not even enabled (to simplify things and reduce rtl build times for tests).

Do you have reproduced the boot loop on you tnCart (not WonderTANG!) boards?

herraa1, 2024-11-09:
> I have tested the tncart on PCB 2.0 on a Philips VG8020 and it gets stuck when starting nextor.sys and a led on the tang lights up. Is there a solution? Thanks.

That description seems to be unrelated to this specific issue.
It should be better that you open a specific issue for the WonderTANG using the tnCart rtl on a Philips VG8020.
Also note that WonderTANG 2.0 is currently not supported by the tnCart github project (it is "supported" in tnCartWonder though), so you should first make sure that any issue with WonderTANG 2.0 can be reproduced also with WonderTANG 1.01c or 1.02d to get support here.

buppu3, 2024-11-09:
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

The tnCart board has not had a bootloop problem yet so far.

herraa1,
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

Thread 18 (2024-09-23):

Problem loading DEMO9990.ROM with TNCROM

herraa1, 2024-09-23:
I made the following test.

I have two WonderTANGs (WTs). I built one tnCartWonder bitstream A with just V9990 and nothing else, and another bitstream B with all except V9990. I flashed WT A with bitstream A and WT B with bitstream B.

I inserted WT A (V9990) in slot 1 and WT B (Nextor, RAM, SCC, FM, SD, ...) in slot 2 of one of my MSX.
I turned on the MSX and it booted correctly, and I tried to load DEMO9990.ROM from [Tiny Yarou](https://www.youtube.com/watch?v=I6kXyMaED0s) with tncrom using:

~~~shell
TNCROM /T KONAMI /R DEMO9990.ROM
~~~

The tncrom tool loaded the rom, rebooted the computer and the rom executed.
But on the welcome screen where you can press [1] or [2] to launch any of the two demos included, when you press [1] or [2] instead of lauching the demos, the welcome screen appears again and again (allowing you to press [1] or [2] but behaving in the same way).

If instead of using tncrom I use SofaRun, the DEMO9990.ROM loads correctly and I can launch the demos without problems by pressing [1] or [2].

I'm using TNCROM 0.0.6.

I tested with the same results both my Omega Home Computer and my Panasonic FSA1-WSX.

I tested too using a FlashJack cartridge instead of the WT B, and loading the DEMO9990.ROM with FROM (the native tool to load ROMs using a FlashJacks) worked correctly too.

So it seems there is still some problem with TNCROM.

buppu3, 2024-09-24:
What is your intention in using "KONAMI"?
This demo works in "ASCII16K".
TNCROM does not support patching for bank switching like SofaRun does.

herraa1, 2024-09-24:
Oh, yes, you are completely right, the rom should be loaded with an ASCII 16K rom mapper...

I verified that it works correctly using the `/T ASCII16` option using TNCROM.
And I confirmed that the FROM utility of the Flashjacks reports that it uses an ASCII16K mapper, and SofaRun reports that it is using an ASCII16W mapper.

I suppose I got fooled because the rom loaded (and kind of worked) in the first place without noticing that I was using the wrong mapper.

I guess it is not easy nor reliable to automatically detect which mapper type uses each rom.
For what I've read, some solutions use an external database to determine the mapper type (mapping a rom checksum to a mapper type), others try to guess the mapper type by looking at some signatures or by looking at the potential number of writes the rom does to the mapper address registers like in [openMSX](https://github.com/openMSX/openMSX/blob/master/src/memory/RomFactory.cc#L63).
Maybe the latter could be incorporated into TNCROM to reduce mistakes like mine.

Thanks!

buppu3, 2024-09-24:
Yes, it would be. It would be useful to have a function to detect it automatically.

It would be sure to refer to a database from hash values like OpenMSX, but it is difficult to create a database for TNCROM from scratch, and it is also difficult to use database references from other software due to licensing reasons.
In this case, although it is not a reliable method, searching for “LD (nnnn),A” while transferring the ROM image file would be more realistic.

herraa1, 2024-09-25:
Thanks for your comments.
I'm closing this issue, as it is solved/clarified.

I'll play a bit with the autodetection of megarom mappers for tncrom.

Closed 2024-09-25.

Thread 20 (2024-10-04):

1chipMSX で IKASCC が動かない

buppu3, 2024-10-04:
1chip MSX で IKASCC が動きません。
IKASCCを同期モード(IMPL_TYPE=0)で使用していますが、1chip MSX で使用するとアドレスバス信号の保持時間が短い為、レジスタ更新タイミングでアドレスが不正になり、レジスタの更新ができません。

buppu3, 2024-10-05:
WR_n, RD_n エッジでアドレスを保持するように修正すると正常に動作する

Closed 2024-10-05.

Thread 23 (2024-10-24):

OPLL broken on latest bitstreams

herraa1, 2024-10-24:
Bitstreams available on commit 87147318e94f9c1714bb793093769dbe42abea7a produce incorrect OPLL audio on WonderTANG! V1.01c and V1.02d boards (no tnCart board available to test here). The other audio sources (PSG and SCC) are fine.

pakoto, 2024-10-24:
same here. Panasonic FS-A1 with Wondertang 2.0, obtain bad OPLL sound.

Msxinfo, 2024-10-24:
Same here. Philips NMS 8250 with WonderTANG 2.0b produces corrupt opll SOUND.

herraa1, 2024-10-24:
I've identified the commit that breaks the OPLL and that is 5261460c80fd7b0aaf43bb109ddbedc49d6cd2b5 "[Add IKASCC module and modify bus timing accordingly](https://github.com/buppu3/tnCart/commit/5261460c80fd7b0aaf43bb109ddbedc49d6cd2b5)".
The previous commit 414c2a9d61bc6059663f97c5fd513c49fcdfd826 "[Add a new sync mode to uma.sv](https://github.com/buppu3/tnCart/commit/414c2a9d61bc6059663f97c5fd513c49fcdfd826)" has OPLL working fine.

herraa1, 2024-10-24:
BTW, The OPLL keeps broken on 455e42b58e218867b44ea48d1c4815b9158110c7 "[fix](https://github.com/buppu3/tnCart/commit/455e42b58e218867b44ea48d1c4815b9158110c7) https://github.com/buppu3/tnCart/issues/20 [IKASCC malfunctions on 1chipMSX](https://github.com/buppu3/tnCart/commit/455e42b58e218867b44ea48d1c4815b9158110c7)" just in case someone was wondering if that fixed it.

herraa1, 2024-10-24:
Rebasing and getting rid of the two commits 5261460c80fd7b0aaf43bb109ddbedc49d6cd2b5 and 455e42b58e218867b44ea48d1c4815b9158110c7 fixes the OPLL problem.

buppu3, 2024-10-26:
It appears that the OPLL malfunctions when using the 27 MHz onboard oscillator.

buppu3, 2024-10-26:
After investigating the cause, we found that Bus.CLK_EN_21M is not generated correctly when using the on-board 27MHz, and OPLL does not operate at the correct 3.58MHz timing.

herraa1, 2024-10-26:
Thanks, I confirm that it is indeed fixed.

Closed 2024-10-26.

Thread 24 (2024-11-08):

Tncart does not work with Ghoauld

xKNIGHTMAREx, 2024-11-08:
I have a VG8020 that I have been able to revive thanks to Ghoauld, it works perfectly with all the cartridges I have tried and with the Wondertang, now with the Tncartwonder when it starts up the first screen that detects the SD appears, the image of the nextor.sys and it goes to Basic. Is there any way to fix this? I would like to be able to use the tncart together with the Ghoauld. The PCB is 2.0b. Thanks.

buppu3, 2024-11-09:
You wrote in issue#14, is this a separate issue from that?
Is it possible to get a list of files with the FILES command after starting BASIC?

xKNIGHTMAREx, 2024-11-09:
Then I try to do it and see what happens.

xKNIGHTMAREx, 2024-11-09:
It says Files not found

xKNIGHTMAREx, 2024-11-09:
https://github.com/user-attachments/assets/dd868715-1963-47da-a41b-c39fb9494a40

xKNIGHTMAREx, 2024-11-09:
The interference is due to the Ghoauld HDMI to VGA adapter

xKNIGHTMAREx, 2024-11-09:
This video is loading the wondertang

https://github.com/user-attachments/assets/37e12153-1f60-43b9-874f-2e624a636250

Chandler-Kluser, 2024-11-09:
[@jabadia](https://github.com/jabadiagm)

buppu3, 2024-11-09:
> It says Files not found

Is the response to the FILES command “file not found” instead of “i/o error” etc.?

polileco, 2024-11-09:
Are you using the same uSD for both cores on the same cartridge? And you did the partition on uSD using WonderTANG?

Can you tell what is the Nextor kernel version of both TnCart and WonderTANG?

What device and partitions "CALL FDISK" command show when runing from BASIC from both cores?

Regards

xKNIGHTMAREx, 2024-11-09:
The version I put in the Tncartwonder is the one on GitHub and for the wondertang the one on its GitHub

xKNIGHTMAREx, 2024-11-09:
Nextor 2.1.2 for Tncartwonder and Nextor 2.1.1 for Wondertang

xKNIGHTMAREx, 2024-11-09:
When I put files now this appears
![Uploading IMG20241109154639.jpg…]()

polileco, 2024-11-09:
How about FDISK?

If the uSD is the same for both cores maybe you can try downgrade only nextor kernel to 2.1.1 on TnCart.

xKNIGHTMAREx, 2024-11-09:
If I run Call Fdisk with the Wondertang it lets me format the SD and create a 4G partition, but if I do it with the one that Tncartwonder has, it only lets me create a 128mb partition.

xKNIGHTMAREx, 2024-11-09:
Uploading VID-20241109-WA0036.mp4…

xKNIGHTMAREx, 2024-11-09:
https://github.com/user-attachments/assets/51789c32-5888-4f8f-ad15-3d5c0c72283c

xKNIGHTMAREx, 2024-11-09:
However, from the wondertang it does make the files for me
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

xKNIGHTMAREx, 2024-11-09:
I have tried with nextor 2.1.0 and 2.1.1 megaflashsdscc-1.slot.rom and it does the same.

buppu3, 2024-11-16:
Both tnCart and goauld multiplex the bus and the timings may not match.
Asserting the WAIT signal on the Z80 during TF access is expected to reduce the amount of data missed.
The WAIT signal can be controlled by synthesizing the USE_WAIT_SIGNAL parameter of the TF_CONTROLLER module with 1.

xKNIGHTMAREx, 2024-11-16:
How do I put 1 in that module?

buppu3, 2024-11-16:
If you want it right away, you have to install Gowin FPGA Designer, modify a part of tnCartWonder, and synthesize the bitstream file.
The part to change is USE_WAIT_SIGNAL = 0 at line 40 of "rtl/src/peripheral/msx/tf_controller.sv" in the tnCartWonder repository.

xKNIGHTMAREx, 2024-11-16:
I'll try to do it, although I don't know if I'll be able to do it well.

Chandler-Kluser, 2024-11-16:
> Both tnCart and goauld multiplex the bus and the timings may not match. Asserting the WAIT signal on the Z80 during TF access is expected to reduce the amount of data missed. The WAIT signal can be controlled by synthesizing the USE_WAIT_SIGNAL parameter of the TF_CONTROLLER module with 1.

well, goa'uld works with wondertang, which actually also multiplexes address bus...

xKNIGHTMAREx, 2024-11-16:
The Wondertang 2.0 works perfectly with the Ghoauld, but the Tncartwonder on the 2.0 board doesn't, it boots up the computer and always goes to Basic. Could someone modify the .fs and put the file on GitHub? I've tried to do it but I have no idea, thanks a lot.

buppu3, 2024-11-17:
> > Both tnCart and goauld multiplex the bus and the timings may not match. Asserting the WAIT signal on the Z80 during TF access is expected to reduce the amount of data missed. The WAIT signal can be controlled by synthesizing the USE_WAIT_SIGNAL parameter of the TF_CONTROLLER module with 1.
>
> well, goa'uld works with wondertang, which actually also multiplexes address bus...

WonderTANG and tnCart have completely different Nextor driver implementation methods, which is probably why this phenomenon occurs.
WonderTANG is a highly functional implementation that performs initial card settings, etc. within the FPGA, while tnCart only performs SPI conversion and initial settings, etc. are performed by the MSX driver software.
The tnCart may have failed to read the CSD during the initialization process, causing it to behave strangely.

xKNIGHTMAREx, 2024-11-17:
Y modificando está línea "USE_WAIT_SIGNAL = 0" a 1 funcionará?. Podrías modificarlo y así lo pruebo, te lo agradecería mucho. Gracias 😊.

xKNIGHTMAREx, 2024-11-17:
And modifying this line "USE_WAIT_SIGNAL = 0" to 1 will work? Could you modify it so I can test it, I would really appreciate it. Thanks 😊.

buppu3, 2024-11-17:
> And modifying this line "USE_WAIT_SIGNAL = 0" to 1 will work? I will try to modify it to see if it works.

I do not know why Nextor does not work on your machine, so I cannot say for sure if it will work with this fix.
I suggested this as one possible cause.

xKNIGHTMAREx, 2024-11-17:
I'll try it and comment here.

xKNIGHTMAREx, 2024-11-17:
I have changed the parameter 0 to 1 and it still doesn't work.

https://github.com/user-attachments/assets/e3536435-86ad-436a-bc51-45b5c3f9a006

buppu3, 2024-11-19:
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

Are you flashing the files created by the rebuild?
New files will be created in "rtl/impl/pnr/"

Also, do functions other than Nextor work?

xKNIGHTMAREx, 2024-11-19:
Yes, use the .fs from that folder, it is supposed to be the one you created. I am having problems with the computer where I have Ghoauld, until I fix it I will not be able to continue testing. When it is ready, let me know and we will continue testing.

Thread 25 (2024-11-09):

TnCart hangs when turbo mode of Panasonic 2+ machines is turned on

polileco, 2024-11-09:
Some titles, especially games, when activated turbo mode, causes the machine to crash. [Ghosts'n'Goblins](https://download.file-hunter.com/Games/MSX2/ROM/Ghosts'n%20Goblins%20-%20ASM%20Team%20(2020)%20[V9990%20Demo]%20[7385].zip), [Life on Earth](https://download.file-hunter.com/Games/MSX2/ROM/Life%20On%20Earth%20-%20Kai%20Magazine%20(2018)%20[Demo%20-%20GFX9000%20needed]%20[original]%20[6946].zip) and [Chibi Akumas](https://www.chibiakumas.com/download/V1666.7z) are some examples.

buppu3, 2024-11-10:
Since tnCart is designed assuming a bus clock of 3.58 MHz, it will not work in the high-speed mode of Panasonic machines.
The SDRAM memory bandwidth is time-divided between the Z80 side and the VDP side, so if the memory timing on the Z80 side is too fast, it will not be able to keep up.
To avoid hang-up, it is necessary to drive the WAIT signal to suppress the Z80 operation.

Msxinfo, 2024-12-22:
Hi Buppu, can you make a solution for the tnCart firmware to work on turboR? It seems to work on the original WonderTang firmware? Is it possible to use that solution on your tnCart firmware as well?

buppu3, 2024-12-22:
What are the specific problems with using turboR?

Msxinfo, 2024-12-24:
> What are the specific problems with using turboR?

Just tested it on a MSX turboR. The turboR starts, but after mentioning the SD card driver the screen freezes and two japanese characters appear on the left upper screen. Sorry, did not make a screenshot.

I tried starting it up in Z80 mode (by pressing 1), but the WT is not recognized and a ''call system' does not go to nextor.
The original WT 2.0b firmware works with turboR. I did not test on 1.02d, but I expect it to work as well. Luis Antoniosi made an adjustment in the firmware. Perhaps you can have a look at the files on his github to see what his solution is?

See Antoniosi's youtube video: https://www.youtube.com/watch?v=VxTeO_pEJkw

buppu3, 2024-12-29:
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

Will Nextor work on [this branch](https://github.com/buppu3/tnCart/issues/develop-new-uma-timing)?

Msxinfo, 2024-12-29:
I will test it this week. Thanks for your effort!

herraa1, 2025-01-05:
> Will Nextor work on [this branch](https://github.com/buppu3/tnCart/tree/develop-new-uma-timing)?

The Omega hangs too with that branch on a Wondertang 1.02d (the main branch works fine though).
It either freezes when showing the SD Card Nextor driver or at a later stage. Some times it drops to basic.

Msxinfo, 2025-01-05:
The original WT 2.0b firmware works on turboR. I will also test if that is also the case with the original WT 1.02d firmware. Luis Felipe has made an adaption for turboR in his firmwares. Thus technically we may assume that it can be integrated in tnCard firmware as well? But for me that is easier said then done. I'm no programmer.

Msxinfo, 2025-01-23:
Any news concerning the tnCart firmware for WonderTang on turboR?

buppu3, 2025-03-02:
> Any news concerning the tnCart firmware for WonderTang on turboR?

It was confirmed that the system runs out of control when booted in R800 mode.
When powering on and booting in Z80 mode while holding down the “1” key, commands such as “CALL FDISK” seem to work.

This appears to be a malfunction caused by the UMA function, which increases memory latency.
If the V9990 and UMA functions are disabled, Nextor will work in R800 mode.

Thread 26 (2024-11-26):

tnCart hangs when running sr.com from slot1 in National CF-3300

herraa1, 2024-11-26:
Luis Felipe Antoniosi reports that his [National CF-3300](https://www.msx.org/wiki/National_CF-3300) freezes (and needs a power cycle to recover, a reset doesn't help) when running SR.COM (SofaRun) after booting his WonderTANG! + tnCart RTL on slot1. When the machine hangs, the led blinks continuosly.
If he uses slot2 instead of slot1, then the freeze doesn't happen.
See [related thread on MRC](https://www.msx.org/forum/msx-talk/hardware/wondertang-who-wants-to-juice-up-your-msx?page=77).

herraa1, 2025-01-05:
I think this issue can be closed. There's no further input from the OP.

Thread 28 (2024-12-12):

Red background on hdmi with v9990 implementation on WT

Msxinfo, 2024-12-12:
I have a bunch of Tang Nano 20 boards that I flashed with the tnCart Wonder firmware so I can use V9990 emulation on my WonderTang 2.00b cartridges.

I noticed that on quite a few boards I get a red background where it should be black. For instance with Eggbert and the Tiny Yarou v9990 demo. Any idea what the problem can be? I

Msxinfo, 2024-12-12:
![Uploading IMG_20241212_172949076_HDR.jpg…]()

Msxinfo, 2024-12-12:
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

buppu3, 2024-12-22:
Does this happen every time?
Or is this a phenomenon that reproduces itself after certain operations?

Msxinfo, 2024-12-23:
This happens every time, but only on specific Tang Nano 20K. Some work fine, but others have this strange behaviour.

herraa1, 2025-01-05:
Is the issue related to specific Tang Nano 20k boards or to the WonderTang PCBs?
Does the same Tang Nano 20k board always show a red background irrespective of which PCB are you using (change the Tang Nano 20k board between your available PCBs)?
And the Tang Nano 20k boards that work fine, do they work fine on PCBs where other Tang Nano 20k boards show a red background?
Are those Tang Nano 20k boards that show a red background from different batches (or do they have a slightly different model number)?

Msxinfo, 2025-01-05:
It happens both on 1.02d as 2.0b boards. It is not the WonderTang hardware, because when I replace the Tn20K the problem is sometimes gone or is still there. I have tested a lot of Tang Nano 20k boards from different batches (about 15). With or without the pin headers presoldered. The TN20k remains giving red backgrounds on different WT pcb's.

Could it be related to the flashing in Windows with certain Gowin programmer versions? What version are you using? One time I flashed a 'red' TN20k with another firmware and the problem was not there, but that didn't work on another TN20K. Could it be the incompleteness of the v9990 emulation?

herraa1, 2025-01-05:
I don't think the programmer should be an issue.
I use Linux and the GOWIN EDA V1.9.9.03 Education Build(73833).

Are you using the .fs from this repo's main branch on 1.02d? Or are you building your own .fs?
Are the "red" Tang Nano 20K new or used?
I assume that the red background is just on the HDMI output of the V9990.

Msxinfo, 2025-01-05:
All the TN20k are new. I use your wondertang2.0b firmware and also 1.02d firmware from this branch. I have also used a firmware provided from pakoto (with SCC enabled and a better mixing of the sound). One time I reflashed a TN20K with your firmware and that solved the problem, but I could not reproduce it on another TN20K. That's the weird part

Red background is indeed on the HDMI output only.

herraa1, 2025-01-05:
I recall seeing a red background too on the very early stages of the project, when there were more apparent video issues, but not since then.

Does the red background happen on different MSX machines and different HDMI monitors?

Can you please try flashing this previous .fs on your 1.02d and see if something changes?
https://github.com/buppu3/tnCart/blob/9bbefbed26447f42592960f6ec74c0ec76d4bfba/rtl/impl/pnr/tnCart_board_wt102d.fs

Msxinfo, 2025-01-07:
So, I did a test of 8 WT boards. 3 of them are WT1.02d and 5 are WT2.00b. i installed the latest Gowin programmer on another computer and downloaded the firmware you provided here for the 1.02d and the one for 2.00b that you provide on your tnCart Wonder repo. I noticed that the Tiny Yarou tech demo is now showing a proper black background on all TN20K boards. So that is a win!

The game Eggbert only did show correct background  colour with two TN20K boards. The other boards give a dark red, a dark blue or a green background. Not really a problem if it is only this game.

herraa1, 2025-01-07:
Great. In order to narrow down the problem a bit more, could you please flash again the [latest .fs for WonderTANG! 1.02d](https://github.com/buppu3/tnCart/blob/main/rtl/impl/pnr/tnCart_board_wt102d.fs) just to confirm that simply changing the .fs (and not the computer or the Gowin programmer version) you can reproduce the problem again?

Msxinfo, 2025-01-07:
Oke, will try.

herraa1, 2025-01-08:
So if I understand it correctly you were not able to reproduce exactly the same problem as before, but you still get some background color issues. Isn’t it?

Msxinfo, 2025-01-09:
Yes, that is correct.

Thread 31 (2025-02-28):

Issue with YJK color decode

lintweaker, 2025-02-28:
I am having some issue with YJK color decode. It does not display the correct colors and also seem to use the same color for multiple pixels.
Checking the FPGA code, YJK and YUV decode should be there.

I've attached two pictures:
- b1-yjk-real-v9990-ok.jpg - captured from a real V9990 in B1 mode with YJK
- b1-yjk-t9990-wrong-decode.jpg - captured from FPGA with Tiny V9990 with YJK decode issues.

If you need more info, let me know. Would be great to get it fully working (Tiny9990 is a awesome to have!)

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

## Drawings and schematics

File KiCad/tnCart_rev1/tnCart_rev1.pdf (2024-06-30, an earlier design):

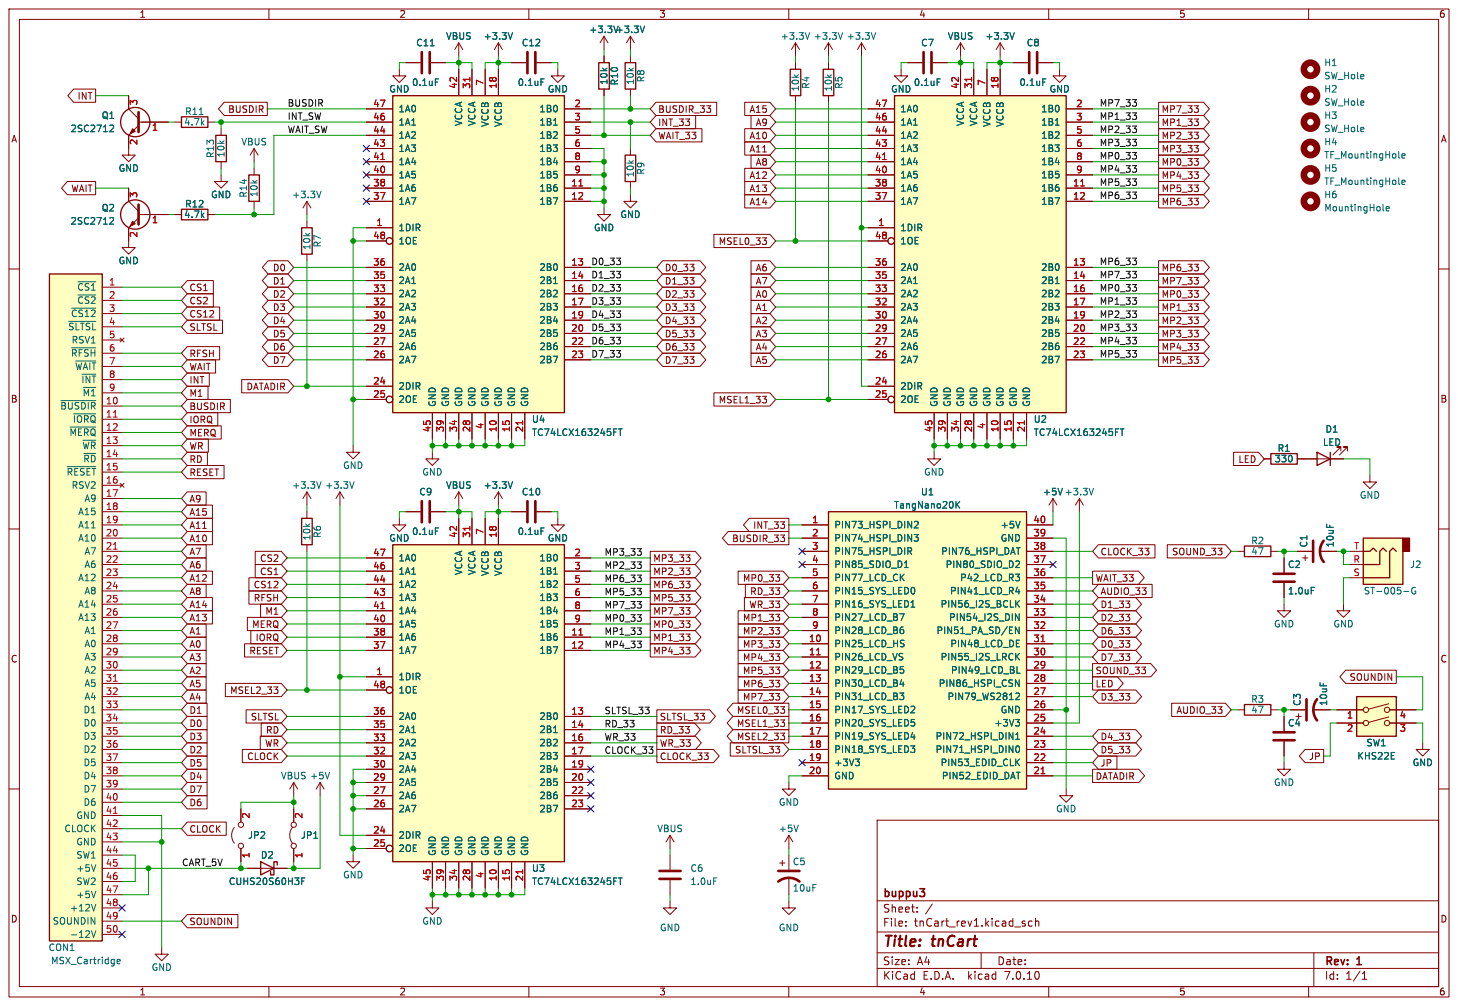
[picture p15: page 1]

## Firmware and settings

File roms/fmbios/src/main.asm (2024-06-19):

;
; main.asm
;
; BSD 3-Clause License
; 
; Copyright (c) 2024, Shinobu Hashimoto
; 
; Redistribution and use in source and binary forms, with or without
; modification, are permitted provided that the following conditions are met:
; 
; 1. Redistributions of source code must retain the above copyright notice, this
;    list of conditions and the following disclaimer.
; 
; 2. Redistributions in binary form must reproduce the above copyright notice,
;    this list of conditions and the following disclaimer in the documentation
;    and/or other materials provided with the distribution.
; 
; 3. Neither the name of the copyright holder nor the names of its
;    contributors may be used to endorse or promote products derived from
;    this software without specific prior written permission.
; 
; THIS SOFTWARE IS PROVIDED BY THE COPYRIGHT HOLDERS AND CONTRIBUTORS "AS IS"
; AND ANY EXPRESS OR IMPLIED WARRANTIES, INCLUDING, BUT NOT LIMITED TO, THE
; IMPLIED WARRANTIES OF MERCHANTABILITY AND FITNESS FOR A PARTICULAR PURPOSE ARE
; DISCLAIMED. IN NO EVENT SHALL THE COPYRIGHT HOLDER OR CONTRIBUTORS BE LIABLE
; FOR ANY DIRECT, INDIRECT, INCIDENTAL, SPECIAL, EXEMPLARY, OR CONSEQUENTIAL
; DAMAGES (INCLUDING, BUT NOT LIMITED TO, PROCUREMENT OF SUBSTITUTE GOODS OR
; SERVICES; LOSS OF USE, DATA, OR PROFITS; OR BUSINESS INTERRUPTION) HOWEVER
; CAUSED AND ON ANY THEORY OF LIABILITY, WHETHER IN CONTRACT, STRICT LIABILITY,
; OR TORT (INCLUDING NEGLIGENCE OR OTHERWISE) ARISING IN ANY WAY OUT OF THE USE
; OF THIS SOFTWARE, EVEN IF ADVISED OF THE POSSIBILITY OF SUCH DAMAGE.
;

; zcc +z80 -startup=-1 -o..\bin\fmbios.rom main.asm driver.asm -create-app -Cz"--rombase=0x4000 --romsize=0x4000"

        DEFC    RDSLT = 000Ch
        DEFC    CALSLT = 001Ch
        DEFC    RSLREG = 0138h
        DEFC    EXPTBL = 0FCC1h
        DEFC    SLTTBL = 0FCC5h
        DEFC    SLTWRK = 0FD09h

        SECTION CODE

        EXTERN  DRV_INIT
        EXTERN  DRV_START
        EXTERN  DRV_STOP
        EXTERN  DRV_CHECK
        EXTERN  DRV_HANDLER

;==============================
; WRITE OPLL REGISTER
;   IN  A = REG#
;       E = DATA
;   OUT none
;==============================
        PUBLIC  WRTOPL
WRTOPL:
        OUT     (7Ch), A
        PUSH    AF
        LD      A,E
        OUT     (7Dh), A
        LD      A, (7FF6h)
        LD      A, (7FF6h)
        LD      A, (7FF6h)
        LD      A, R
        POP     AF
        RET

        LD      (7FF4h),A
        ; 3.36usec(12.03clk)
        PUSH    AF              ; 12
        LD      A,E             ;  5
        LD      (7FF5h),A
        ; 23.52u(84.20clk)
        LD      A, (7FF6h)      ; 14
        LD      A, (7FF6h)      ; 14
        LD      A, (7FF6h)      ; 14
        LD      A, R            ; 10
        POP     AF              ; 11
        RET                     ; 11
                                ; 11

;==============================
; READ DATA
;   IN  HL = DST ADDR
;       A = SOUND#
;   OUT none
;   USE F
;==============================
        PUBLIC  RDDATA
RDDATA:
        PUSH    AF
        PUSH    BC
        PUSH    DE
        PUSH    HL

        PUSH    HL

        ; HL = A * 8
        LD      L, A
        LD      H, 0
        ADD     HL, HL
        ADD     HL, HL
        ADD     HL, HL

        ; HL += 0x4C00
        LD      DE, 4C00h
        ADD     HL, DE

        ; DE = dst address
        POP     DE

        ; BC = 8
        LD      BC, 8

        ; memcpy(DE, HL, BC)
        LDIR

        POP     HL
        POP     DE
        POP     BC
        POP     AF
        RET

;==============================
; INTIALIZE OPLL
;   IN  HL = WORK AREA ADDRESS
;   OUT none
;   USE AF,BC,DE,HL,IX,IY
;==============================
        PUBLIC  INIOPL
INIOPL:
        ; ワークアドレス保存
        PUSH    HL
        CALL    SETWRK

        ; IX = (WORK_t*)HL
        POP     IX

        ; 内蔵 FM 音源を探す
        CALL    SEARCH_APRLOPLL
        JP      C, SKIP_ENABLE_IO

        ; 内蔵 FM 音源が無いなら自分の I/O ポートを有効にする
        LD      A, (7FF6h)
        OR      1
        LD      (7FF6h), A
SKIP_ENABLE_IO:

        JP      DRV_INIT

;==============================
; START MUSIC
;   IN  HL = DATA ADDRESS
;       A = FLAG
;   OUT none
;   USE AF,BC,DE,HL,IX,IY
;==============================
        PUBLIC  MSTART
MSTART:
        PUSH    AF
        PUSH    HL
        CALL    GETWRK
        POP     HL
        POP     AF
        JP      DRV_START

;==============================
; STOP MUSIC
;   IN  none
;   OUT none
;   USE AF,BC,DE,HL,IX,IY
;==============================
        PUBLIC  MSTOP
MSTOP:
        CALL    GETWRK
        JP      DRV_STOP

;==============================
; BGM END CHECK
;   IN  none
;   OUT A = STATE
;   USE none
;==============================
        PUBLIC  TSTBGM
TSTBGM:
        PUSH    DE
        PUSH    HL
        PUSH    IX
        PUSH    AF
        CALL    GETWRK
        POP     AF
        CALL    DRV_CHECK
        POP     IX
        POP     HL
        POP     DE
        RET

;==============================
; OPLL MUSIC DRIVER INTERRUPT HANDLER
;   IN  none
;   OUT none
;   USE none
;==============================
        PUBLIC  OPLDRV
OPLDRV:
        PUSH    AF
        PUSH    BC
        PUSH    DE
        PUSH    HL
        PUSH    IX
        PUSH    IY
        CALL    GETWRK
        CALL    DRV_HANDLER
        POP     IY
        POP     IX
        POP     HL
        POP     DE
        POP     BC
        POP     AF
        RET

;==============================
; GET SLTWRK ADDR
;   IN  none
;   OUT HL = ADDR
;   USE AF, DE, HL
;==============================
GET_SLTWRK:
        ; 基本スロット番号を取得
        LD      A, (EXPTBL)
        PUSH    AF
        POP     IY                      ; IY = MAIN ROM SLOT
        LD      IX, RSLREG
        CALL    CALSLT

        ; スロットが拡張されているか?
        RRCA
        RRCA
        AND     0b00000011
        LD      E, A                    ; E = ページ1基本スロット番号(0~3)
        LD      D, 0                    ; D = 0
        LD      HL, EXPTBL
        ADD     HL, DE                  ; HL = EXPTBL + ページ1基本スロット番号

        LD      A, (HL)
        AND     0b10000000
        LD      A, 0                    ; A = 0(拡張スロット番号)
        JP      Z, GET_SLTWRK_NOEXP     ; EXPTBL の MSB が 0 ならスキップ

        ; 拡張スロット番号
        LD      HL, SLTTBL
        ADD     HL, DE                  ; HL = SLTTBL + ページ1基本スロット番号
        LD      A, (HL)
        RRCA
        RRCA
        AND     0b00000011              ; A = 拡張スロット番号(0~3)

GET_SLTWRK_NOEXP:
        ; SLTWRK のアドレスを計算
        SLA     E
        SLA     E
        OR      E                       ; A = 基本スロット番号 * 4 + 拡張スロット番号
        ADD     A, A
        ADD     A, A                    ; A = (基本スロット番号 * 4 + 拡張スロット番号) * 4 
        ADD     A, 1                    ; A = (基本スロット番号 * 4 + 拡張スロット番号) * 4 + 1
        ADD     A, A                    ; A = ((基本スロット番号 * 4 + 拡張スロット番号) * 4 + 1) * 2 
        LD      E, A                    ; DE = ((基本スロット番号 * 4 + 拡張スロット番号) * 4 + 1) * 2
        LD      HL, SLTWRK
        ADD     HL, DE                  ; HL = SLTWRK + ((基本スロット番号 * 4 + 拡張スロット番号) * 4 + 1) * 2

        RET

;==============================
; GET WORK ADDR
;   IN  none
;   OUT IX = ADDR
;   USE AF, DE, HL
;==============================
GETWRK:
        CALL    GET_SLTWRK
        LD      E, (HL)
        INC     HL
        LD      D, (HL)
        PUSH    DE
        POP     IX
        RET

;==============================
; SET WORK ADDR
;   IN  HL = ADDR
;   OUT none
;   USE AF, DE, HL
;==============================
SETWRK:
        PUSH    HL
        CALL    GET_SLTWRK
        POP     DE
        LD      (HL), E
        INC     HL
        LD      (HL), D
        RET

;==============================
; 内蔵 OPLL があるかチェック
;   IN  none
;   OUT C FLAG = 0:not found
;                1:found other cartridge
;   USE AF, BC
;==============================
SEARCH_APRLOPLL:
        LD      A, 0
SEARCH_APRLOPLL_LOOP:
        BIT     2, A
        JR      NZ, SEARCH_APRLOPLL_EXIT
        CALL    SEARCH_APRLOPLL_PRIMAY
        RET     C
        INC     A
        JR      SEARCH_APRLOPLL_LOOP
SEARCH_APRLOPLL_EXIT:
        XOR     A
        RET

;==============================
; 指定基本スロットに APRLOPLL があるかチェック
;   IN  A = primary slot number
;   OUT C FLAG = 0:not found
;                1:found other cartridge
;   USE F
;==============================
SEARCH_APRLOPLL_PRIMAY:
        PUSH    HL
        PUSH    DE
        PUSH    BC
        PUSH    AF

        ; if(EXPTBL[A] & 0x80) goto SEARCH_APRLOPLL_PRIMAY_EXP;
        LD      E, A
        LD      D, 0
        LD      HL, EXPTBL
        ADD     HL, DE
        LD      A, (HL)
        AND     80h
        JR      NZ, SEARCH_APRLOPLL_PRIMAY_EXP
        LD      A, E

        ; 指定スロットをチェック
        CALL    CHECK_APRLOPLL

        ; 終わり
SEARCH_APRLOPLL_PRIMAY_EXIT:
        POP     BC
        LD      A, B
        POP     BC
        POP     DE
        POP     HL
        RET

SEARCH_APRLOPLL_PRIMAY_EXP:
        ; 拡張スロット番号を作成
        LD      A, 80h
        OR      E

SEARCH_APRLOPLL_PRIMAY_EXP_LOOP:
        ; 指定スロットをチェック
        CALL    CHECK_APRLOPLL
        JP      C, SEARCH_APRLOPLL_PRIMAY_EXIT

        ; 次のセカンダリスロット
        ADD     A, 04h

        ; セカンダリをすべてチェックした?
        BIT     4, A
        JR      NZ, SEARCH_APRLOPLL_PRIMAY_EXP_LOOP

        ; not found
        XOR     A
        JR      SEARCH_APRLOPLL_PRIMAY_EXIT

;==============================
; 指定スロットに APRLOPLL があるかチェック
;   IN  A = slot number
;   OUT C FLAG = 0:not found
;                1:found other cartridge
;   USE F
;==============================
CHECK_APRLOPLL:
        PUSH    HL
        PUSH    DE
        PUSH    BC
        PUSH    AF

        LD      DE, ID_APRLOPLL
        LD      HL, 4018h
        LD      B, 08h

CHECK_APRLOPLL_LOOP:
        CALL    RDSLT
        EX      DE, HL
        CP      (HL)
        EX      DE, HL
        JR      NZ, CHECK_APRLOPLL_NOT_FOUND

        INC     HL
        INC     DE
        POP     AF
        PUSH    AF

        DJNZ    CHECK_APRLOPLL_LOOP

        SCF
        JR      CHECK_APRLOPLL_EXIT

CHECK_APRLOPLL_NOT_FOUND:
        XOR     A

CHECK_APRLOPLL_EXIT:
        POP     BC
        LD      A, B
        POP     BC
        POP     DE
        POP     HL
        RET

ID_APRLOPLL:
        DEFB   'A', 'P', 'R', 'L', 'O', 'P', 'L', 'L'

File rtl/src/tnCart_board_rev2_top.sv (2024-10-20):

//
// tnCart_board_rev2_top.sv
//
// BSD 3-Clause License
// 
// Copyright (c) 2024, Shinobu Hashimoto
// 
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
// 3. Neither the name of the copyright holder nor the names of its
//    contributors may be used to endorse or promote products derived from
//    this software without specific prior written permission.
// 
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

`default_nettype none

module TNCART_BOARD_REV2_TOP (
    input   wire            CLK_27M,

    // SDRAM
    output  wire            O_sdram_clk,
    output  wire            O_sdram_cke,
    output  wire            O_sdram_cs_n,
    output  wire            O_sdram_cas_n,
    output  wire            O_sdram_ras_n,
    output  wire            O_sdram_wen_n,
    inout   wire    [31:0]  IO_sdram_dq,
    output  wire    [10:0]  O_sdram_addr,
    output  wire    [1:0]   O_sdram_ba,
    output  wire    [3:0]   O_sdram_dqm,

    // BUS
    output  wire            CART_BUSDIR_n,
    output  wire            CART_INT_n,
    output  wire            CART_WAIT_n,
    input   wire            CART_CLOCK,
    input   wire    [5:0]   CART_MUX_SIG,
    output  wire    [1:0]   CART_MUX_CS_A,
    inout   wire    [7:0]   CART_DATA_SIG,

    // SOUND
    output  wire            SOUND_INT,
    output  wire            I2S_SCLK,
    output  wire            I2S_BCLK,
    output  wire            I2S_DIN,
    output  wire            I2S_LRCLK,

    // LED
    output  wire            LED,

    // TMDS
    output wire             tmds_clk_p,
    output wire             tmds_clk_n,
    output wire    [2:0]    tmds_data_p,
    output wire    [2:0]    tmds_data_n,

    // SPI FLASH
    output  wire            mspi_cs,
    output  wire            mspi_sclk,
    input   wire            mspi_miso,
    output  wire            mspi_mosi,
    output  wire            mspi_hold,

    // TF
    output  wire            TF_SCLK,    // SCLK
    output  wire            TF_CMD,     // MOSI
    input   wire            TF_DAT0,    // MISO
    inout   wire            TF_DAT1,    // NC
    inout   wire            TF_DAT2,    // NC
    inout   wire            TF_DAT3,    // CS_n

    // UART
    input   wire            UART_RX,
    output  wire            UART_TX
);

    // UMA を有効
    localparam          ENABLE_UMA              = 1;//CONFIG::ENABLE_V9990;

    /***************************************************************
     * CLOCK
     ***************************************************************/
    logic CLK_BASE/* synthesis syn_keep=1 */;
    logic CLK_BASE_READY;
    logic CLK_MEM;
    logic CLK_MEM_P;
    logic CLK_MEM_READY;
    logic CLK_TMDS_S/* synthesis syn_keep=1 */;
    logic CLK_TMDS_P/* synthesis syn_keep=1 */;
    logic CLK_TMDS_READY;
    logic CLK_21M/* synthesis syn_keep=1 */;
    BOARD_REV1_CLOCK u_clk (
        .RESET_n        (1'b1),
        .CLK_IN         (CONFIG_BOARD::SYNC_CPU_CLK ? CART_CLOCK : CLK_27M),
        .CLK_BASE,
        .CLK_BASE_READY,
        .CLK_MEM,
        .CLK_MEM_P,
        .CLK_MEM_READY,
        .CLK_TMDS_S,
        .CLK_TMDS_P,
        .CLK_TMDS_READY,
        .CLK_21M
    );

    /***************************************************************
     * UART
     ***************************************************************/
    if(CONFIG_BOARD::ENABLE_UART_MODULE) begin
        UART_RX_IF RXD();
        UART_RX #(
            .CLKFREQ            (108_000_000)
        ) u_rxd (
            .RESET_n,
            .CLK,
            .RXD                (UART_RX),
            .Uart_rx_interface  (RXD)
        );

        UART_TX_IF TXD();
        UART_TX #(
            .CLKFREQ            (108_000_000)
        ) u_txd (
            .RESET_n,
            .CLK,
            .TXD                (UART_TX),
            .Uart_tx_interface  (TXD)
        );

        assign RXD.READ = 0;
        assign RXD.CLEAR = 0;
        assign TXD.DATA = 0;
        assign TXD.STROBE = 0;
    end
    else begin
        assign UART_TX = 1;
    end

    /***************************************************************
     * MSX バス
     ***************************************************************/
    wire RESET_n;
    wire CLK = CLK_BASE;
    BUS_IF Bus();

    // リセット信号処理
    reg reset_n = 0;
    assign RESET_n = reset_n;
    always_ff @(posedge CLK_BASE or negedge CLK_BASE_READY or negedge sdram_ready) begin
        if(!CLK_BASE_READY) reset_n <= 0;       // PLL 準備中ならリセット
        else if(!sdram_ready) reset_n <= 0;     // SDRAM 準備中ならリセット
        else reset_n <= 1; 
    end

    // バス信号処理
    BOARD_REV2_BUS u_bus (
        .RESET_n,
        .CLK,
        .CLK_21M,
        .CART_BUSDIR_n,
        .CART_INT_n,
        .CART_WAIT_n,
        .CART_CLOCK,
        .CART_MUX_SIG,
        .CART_MUX_CS_A,
        .CART_DATA_SIG,
        .Bus
    );
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

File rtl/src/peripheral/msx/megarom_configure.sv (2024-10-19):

//
// megarom_configure.sv
//
// BSD 3-Clause License
// 
// Copyright (c) 2024, Shinobu Hashimoto
// 
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
// 3. Neither the name of the copyright holder nor the names of its
//    contributors may be used to endorse or promote products derived from
//    this software without specific prior written permission.
// 
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

`default_nettype none

/***********************************************************************
 * メガロムコントローラー設定モジュール
 ***********************************************************************/
//  0000h   キー0
//  0001h   キー1
//  0002h   キー2
//  0003h   キー3
//  000Ch   フラグ
//              b0  ライトプロテクト(1=書き込み禁止/0=書き込み許可)
//              b1  バンクサイズ(0=8KB/1=16KB)
//              b2  CS1マスク(1=4000h~7FFFh アクセス不可/0=アクセス可能)
//              b3  CS2マスク(1=8000h~BFFFh アクセス不可/0=アクセス可能)
//              b4  SCC 許可(1=有効/0=無効)
//  000Dh   バンクレジスタデータマスク
//  000Eh   バンクレジスタアドレスマスク下位
//  000Fh   バンクレジスタアドレスマスク上位
//  0010h   BANK#0 レジスタアドレス下位
//  0011h   BANK#0 レジスタアドレス上位
//  0012h   BANK#0 初期値
//  0013h   予約
//  0014h   BANK#1 レジスタアドレス下位
//  0015h   BANK#1 レジスタアドレス上位
//  0016h   BANK#1 初期値
//  0017h   予約
//  0018h   BANK#2 レジスタアドレス下位
//  0019h   BANK#2 レジスタアドレス上位
//  001Ah   BANK#2 初期値
//  001Bh   予約
//  001Ch   BANK#3 レジスタアドレス下位
//  001Dh   BANK#3 レジスタアドレス上位
//  001Eh   BANK#3 初期値
//  001Fh   予約

module MEGAROM_CONFIGURE #(
    parameter [23:0]    FLASH_FS_ADDR               = 0,
    parameter [23:0]    FLASH_FS_SIZE               = 0,
    parameter [23:0]    FLASH_MEGAROM_ADDR          = 0,
    parameter [23:0]    FLASH_MEGAROM_SIZE          = 0,
    parameter [23:0]    FLASH_NEXTOR_ADDR           = 0,
    parameter [23:0]    FLASH_NEXTOR_SIZE           = 0,
    parameter [23:0]    FLASH_FM_ADDR               = 0,
    parameter [23:0]    FLASH_FM_SIZE               = 0,
    parameter [23:0]    FLASH_PAC_ADDR              = 0,
    parameter [23:0]    FLASH_PAC_SIZE              = 0,
    parameter [23:0]    RAM_ADDR                    = 0,
    parameter [23:0]    RAM_SIZE                    = 0,
    parameter [15:0]    BASE_ADDR                   = 0,
    parameter [7:0]     DEFAULT_BANK_REG_INIT_0     = 0,
    parameter [7:0]     DEFAULT_BANK_REG_INIT_1     = 0,
    parameter [7:0]     DEFAULT_BANK_REG_INIT_2     = 0,
    parameter [7:0]     DEFAULT_BANK_REG_INIT_3     = 0,
    parameter [15:0]    DEFAULT_BANK_REG_ADDR_0     = 16'hFFFF,
    parameter [15:0]    DEFAULT_BANK_REG_ADDR_1     = 16'hFFFF,
    parameter [15:0]    DEFAULT_BANK_REG_ADDR_2     = 16'hFFFF,
    parameter [15:0]    DEFAULT_BANK_REG_ADDR_3     = 16'hFFFF,
    parameter [15:0]    DEFAULT_BANK_REG_ADDR_MASK  = 16'h0000,
    parameter [7:0]     DEFAULT_BANK_REG_MASK       = 8'h00,
    parameter [0:0]     DEFAULT_WRITE_PROTECT       = 1'b1,
    parameter [0:0]     DEFAULT_IS_16K_BANK         = 1'b1,
    parameter [0:0]     DEFAULT_CS1_MASK            = 1'b1,
    parameter [0:0]     DEFAULT_CS2_MASK            = 1'b1,
    parameter [0:0]     DEFAULT_SCC_ENA             = 1'b0,
    parameter [0:0]     DEFAULT_SCC_I_ENA           = 1'b0,
    parameter [0:0]     DEFAULT_ENABLE_CONTINUOUS   = 1'b0,
    parameter [0:0]     DEFAULT_ENABLE              = 1'b0
) (
    input wire          CLK,
    input wire          RESET_n,
    BUS_IF.CARTRIDGE    Bus,
    XFER_IF.HOST        Xfer,
    MEGAROM_IF.HOST     Megarom,
    output reg          SCC_ENA,
    output reg          SCC_I_ENA
);
    // 00h~1Fh
    localparam [7:0]    KEY_0 = 8'hAB;
    localparam [7:0]    KEY_1 = 8'hCD;
    localparam [7:0]    KEY_2 = 8'h98;
    localparam [7:0]    KEY_3 = 8'h76;
    localparam [4:0]    ADDR_KEY_0                  = 5'h00;
    localparam [4:0]    ADDR_KEY_1                  = 5'h01;
    localparam [4:0]    ADDR_KEY_2                  = 5'h02;
    localparam [4:0]    ADDR_KEY_3                  = 5'h03;
    localparam [4:0]    ADDR_FLAGS                  = 5'h0C;
    localparam [4:0]    ADDR_MASK_VAL               = 5'h0D;
    localparam [4:0]    ADDR_MASK_ADDR_L            = 5'h0E;
    localparam [4:0]    ADDR_MASK_ADDR_H            = 5'h0F;
    localparam [4:0]    ADDR_BANK0_ADDR_L           = 5'h10;
    localparam [4:0]    ADDR_BANK0_ADDR_H           = 5'h11;
    localparam [4:0]    ADDR_BANK0_INIT_VAL         = 5'h12;
    localparam [4:0]    ADDR_BANK0_RESERVED         = 5'h13;
    localparam [4:0]    ADDR_BANK1_ADDR_L           = 5'h14;
    localparam [4:0]    ADDR_BANK1_ADDR_H           = 5'h15;
    localparam [4:0]    ADDR_BANK1_INIT_VAL         = 5'h16;
    localparam [4:0]    ADDR_BANK1_RESERVED         = 5'h17;
    localparam [4:0]    ADDR_BANK2_ADDR_L           = 5'h18;
    localparam [4:0]    ADDR_BANK2_ADDR_H           = 5'h19;
    localparam [4:0]    ADDR_BANK2_INIT_VAL         = 5'h1A;
    localparam [4:0]    ADDR_BANK2_RESERVED         = 5'h1B;
    localparam [4:0]    ADDR_BANK3_ADDR_L           = 5'h1C;
    localparam [4:0]    ADDR_BANK3_ADDR_H           = 5'h1D;
    localparam [4:0]    ADDR_BANK3_INIT_VAL         = 5'h1E;
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

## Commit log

2024-06-18 Added circuit diagram of prototype board
    [tnCart_rev1.kicad_sch]
2024-06-30 Added schematic PDF file.
2024-07-18 Fixed problem with BitBlt failed when the destination address crosses a 32-bit alignment.
    [t9990_blit_fifo.sv]
2024-09-08 Fix hold-path warning in timing analysis.
    [t9990_color_decode.sv]
2024-09-22 Modified PLL clock input to on-board 27MHz until cause is determined.
2024-09-26 Modify disabling of UART module
2024-10-02 Modify config.sv regarding board configuration
2024-10-20 Add a draft schematic for tnCart_rev2
    [tnCart_rev2.kicad_sch]
